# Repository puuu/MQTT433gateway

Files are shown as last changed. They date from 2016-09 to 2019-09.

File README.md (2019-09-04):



# MQTT433gateway

This Project implements a [MQTT](https://en.wikipedia.org/wiki/MQTT)
433.92MHz radio-frequency device gateway.  This is a IoT bridge to
couple popular RF devices like RC power-socket switches or weather
stations to internet capable devices like smartphone and tables.  In
this way they can be integrated into a home automation system.

The Software runs on a ESP8266 micro controller/WiFi chip and process
many 433.92MHz radio-protocols themselves.  The protocols are
processed utilizing the [ESPiLight](https://github.com/puuu/ESPiLight)
Arduino library which is a port of the [pilight](https://pilight.org/)
433.92MHz protocols to the Arduino platform.  The aim is to transmit,
receive and parse many 433.92MHz protocols directly on the device and
publish the results via MQTT.

A list of supported protocols can be found in the pilight manual:
https://manual.pilight.org/protocols/433.92/index.html

## Installation

Firmware binary are provided under
[releases](https://github.com/puuu/MQTT433gateway/releases). If you
want to build from source please have a look at
[Development](#development).  For the first flash you have multiple
possibilities, some of them are:

- Build and flash with PlatformIO (see [Development](#development))
- Flash with [esptool.py](https://github.com/espressif/esptool)
  ```console
  $ esptool.py --port <serialport> write_flash 0 mqtt433gateway_<env>-<version>.bin
  ```
- Flashing the `WebUpdater` example from
  [Arduino](https://github.com/esp8266/Arduino#installing-with-boards-manager)
  (File -> Examples -> ESP8266HTTPUpdateServer) and uploading the
  MQTT433gateway binary via browser.

At the moment two binaries are provided:
- `mqtt433gateway_esp12e-*.bin` generic ESP8266 module with cpu clock
  = 80 MHz (recommend)
- `mqtt433gateway_esp12e_160-*.bin` generic ESP8266 module with cpu
  clock = 160 MHz

The `platformio.ini` provides more environments, but the main
different between these are the way how they are flashed via serial
connector and how additional components (like LEDs) are
connected. Since MQTT433gateway can be fully configured by the web
frontend and provided [over-the-air programming](#ota-update), these
binaries should be sufficient.

## Hardware

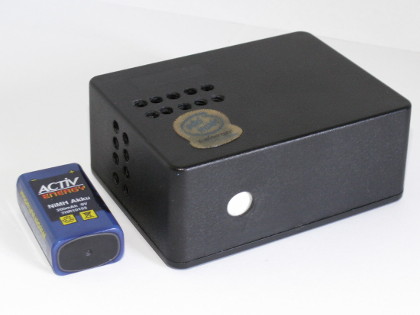
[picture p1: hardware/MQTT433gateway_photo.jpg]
MQTT433gateway box
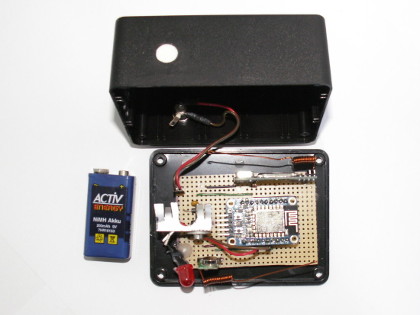
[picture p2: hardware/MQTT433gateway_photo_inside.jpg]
MQTT433gateway box open
 

The Software is primarily written for ESP8266 devices.  It is tested
with an
[Adafruit HUZZAH ESP8266](https://www.adafruit.com/product/2471), but
any other ESP8266 board should be fine too.  The circuitry can be
found in the [`hardware`](hardware/) folder.  The circuitry utilizes a separate 5V
voltage regulator.  This way it is possible to supply the
MQTT433gateway with up to 12V.  The 434MHz transmitter is directly
connected to the power-supply input, thus it can be driven with 12V
which enhances the transmitting range.  But powering with 12V also
means that the voltage regulator dissipates much power and a heat sink
is highly recommended.

For transmitting and receiving you need 434MHz-RF modules.  More
information can be found here:
- https://wiki.pilight.org/receivers
- https://wiki.pilight.org/senders
- https://github.com/sui77/rc-switch/wiki/List_TransmitterReceiverModules

If you are interested in a good receiving range, then I can not
recommend a WRL-10532 module.  I only achieved a range of about 5m
with it, after changing it against a RXB6 receiver, the range
increases to over 30m (including walls).

For the transmitter and receiver module you need separate antennas.
1/4 lambda (17cm) antennas are sufficient, but you may want to try
[coil loaded antennas](https://www.elektor.nl/Uploads/Forum/Posts/How-to-make-a-Air-Cooled-433MHz-antenna.pdf).

### LED status

The MQTT433gateway indicates its status by a LED:
- Connecting to WiFi/startup: Flashing at 1 Hz
- WiFiManager require WiFi configuration: Flashing at 5 Hz
- Device require configuration: Flashing at 0.5 Hz
- Normal operation: Heartbeat pulsing
- OTA Update: on during upload

## Configuration

The device is fully configurable through a web browser.  If you boot it for the
first time, it will create a WiFi access point (default ssid is `rf434`) where
you can connect to.  If you type in any url in your browser, you will get
directed to the WiFi configuration of the device.  You can select your network
here and fill in the credentials.

After that it will stop the access point and connect to your network.  There you
can either discover it via mDNS (default is `rf434.local`), ask your router for
the address of the device or check the serial console output.  If you type this
address in your browser, you'll see the main configuration frontend.  The
default username is `admin`, the default password is `MQTT433gateway`.

Please fill here your MQTT connection details. You can also change the topics
the device will subscribe and publish to.  In addition, all hardware related
settings, like connection pins of transmitter and receiver are configurable.

**Please note:** you have to change the configuration password! For security
reasons the device will not start working before this password is changed.

## MQTT/Automation

The MQTT433gateway communicates via MQTT, therefore a MQTT broker is needed,
e.g., [Mosquitto](https://mosquitto.org/). The topics for receiving and
transmitting can be configured with the `mqttReceiveTopic` and `mqttSendTopic`
settings. They default to `rf434/recv/` and `rf434/send/`, respectively.  It is
possible to use a common topic for multiple gateways in one network and thus to
expand the radio range.

After (re)connecting to the MQTT broker, the gateway sends the message
`{"version":"<git tag or hash>","chipId":"<chipId>"}` to the version
topic that is set in `mqttVersionTopic` as well as the message
`online` to the state topic that is set in `mqttStateTopic`.  In
addition, it registered with the last will set to the message
`offline` for the state topic. This allows to check the status of the
MQTT433gateway, e.g. as a availability topic in Home Assistant.

MQTT subscription is done to the topic `<mqttSendTopic><protocol>`.  The
messages to be transmitted must be a valid pilight JSON messages.  The setting
`mqttSendTopic` should end with a `/`.  `<protocol>` is the pilight protocol
name.  Additionally, `<protocol>` can be `RAW` to transmit a RAW signal similar
as used with the [pilight USB Nano](https://github.com/pilight/pilight-usb-nano/blob/master/pilight_usb_nano.c).

Received and decoded RF signals are published in the
`<mqttReceiveTopic><protocol>[/<id>]` topic as pilight JSON message.  To
avoid receiving errors, a message must be received at least twice
before it is published.  `<protocol>` is the pilight protocol name and
the optional `<id>` will be used if the pilight JSON message contains
an `id` attribute.

### Integration in Home Assistant

Here are some examples how to integrate the MQTT433gateway into
[Home Assistant](https://home-assistant.io).

Status of the MQTT433gateway:

```yaml
binary_sensor:
  - platform: mqtt
    state_topic: "rf434/state"
    name: "rf434"
    payload_on: "online"
    payload_off: "offline"
    device_class: connectivity
```

The message of a TCM 218943 weather station sensor looks like this:
`rf434/recv/tcm/108 {"id":108,"temperature":22.7,"humidity":50,"battery":1,"button":0}`.
A corresponding Home Assistant configuration is:

```yaml
sensor:
  - platform: mqtt
    state_topic: "rf434/recv/tcm/108"
    unit_of_measurement: "°C"
    name: "tcm_a_temp"
    value_template: '{{ value_json.temperature }}'
    device_class: temperature
    availability_topic: "rf434/state"
  - platform: mqtt
    state_topic: "rf434/recv/tcm/108"
    unit_of_measurement: "%"
    name: "tcm_a_humidity"
    value_template: '{{ value_json.humidity }}
    device_class: humidity
    availability_topic: "rf434/state"

binary_sensor:
  - platform: mqtt
    state_topic: "rf434/recv/tcm/108"
    name: "tcm_a_battery"
    sensor_class: power
    payload_on: 0
    payload_off: 1
    value_template: '{{ value_json.battery }}'
    device_class: battery
    availability_topic: "rf434/state"
```

Impulse RC socket switches, like many RC socket switches with DIP
switches:

```yaml
switch:
  - platform: mqtt
    name: "impuls_24_1"
    command_topic: "rf434/send/impuls"
    payload_on: '{"systemcode":24,"programcode":1,"on":1}'
    payload_off: '{"systemcode":24,"programcode":1,"off":1}'
    availability_topic: "rf434/state"
  - platform: mqtt
    name: "impuls_24_2"
    command_topic: "rf434/send/impuls"
    payload_on: '{"systemcode":24,"programcode":2,"on":1}'
    payload_off: '{"systemcode":24,"programcode":2,"off":1}'
    availability_topic: "rf434/state"
  - platform: mqtt
    name: "impuls_24_3"
    command_topic: "rf434/send/impuls"
    payload_on: '{"systemcode":24,"programcode":4,"on":1}'
    payload_off: '{"systemcode":24,"programcode":4,"off":1}'
    availability_topic: "rf434/state"
```

Elro 800 based RC socket switches:

```yaml
switch:
  - platform: mqtt
    name: "elro800_13_A"
    command_topic: "rf434/send/elro_800_switch"
    payload_on: '{"systemcode":13,"unitcode":1,"on":1}'
    payload_off: '{"systemcode":13,"unitcode":1,"off":1}'
    availability_topic: "rf434/state"
  - platform: mqtt
    name: "elro800_13_B"
    command_topic: "rf434/send/elro_800_switch"
    payload_on: '{"systemcode":13,"unitcode":2,"on":1}'
    payload_off: '{"systemcode":13,"unitcode":2,"off":1}'
    availability_topic: "rf434/state"
  - platform: mqtt
    name: "elro800_13_C"
    command_topic: "rf434/send/elro_800_switch"
    payload_on: '{"systemcode":13,"unitcode":4,"on":1}'
    payload_off: '{"systemcode":13,"unitcode":4,"off":1}'
    availability_topic: "rf434/state"
  - platform: mqtt
    name: "elro800_13_D"
    command_topic: "rf434/send/elro_800_switch"
    payload_on: '{"systemcode":13,"unitcode":8,"on":1}'
    payload_off: '{"systemcode":13,"unitcode":8,"off":1}'
    availability_topic: "rf434/state"
```

Quigg GT9000 based RC socket switches, e.g., Tevion GT-9000,
SilverCrest 91210 or Intertek Unitec 48110:

```yaml
switch:
  - platform: mqtt
    name: "gt9000_590715_0"
    command_topic: "rf434/send/quigg_gt9000"
    payload_on: '{"id":590715,"unit":0,"on":1}'
    payload_off: '{"id":590715,"unit":0,"off":1}'
    availability_topic: "rf434/state"
  - platform: mqtt
    name: "gt9000_590715_2"
    command_topic: "rf434/send/quigg_gt9000"
    payload_on: '{"id":590715,"unit":2,"on":1}'
    payload_off: '{"id":590715,"unit":2,"off":1}'
    availability_topic: "rf434/state"
  - platform: mqtt
    name: "gt9000_590715_3"
    command_topic: "rf434/send/quigg_gt9000"
    payload_on: '{"id":590715,"unit":3,"on":1}'
    payload_off: '{"id":590715,"unit":3,"off":1}'
    availability_topic: "rf434/state"
```

## OTA Update

Updates of the MQTT433gateway can be preformed by OTA (Over-the-air
programming) via the web frontend.  To do this, you need the binary
file that can be found under
[releases](https://github.com/puuu/MQTT433gateway/releases) or, if you
build with PlatformIO, at `<BUILD_DIR>/firmware.bin`,
e.g. `.pio/build/esp12e/firmware.bin`.

## Debugging/RF-protocol analyzing

The MQTT433gateway has a powerful logging system based on
[ArduinoSimpleLogging](https://github.com/janLo/ArduinoSimpleLogging).  Messages
for different log levels can be logged to serial interface, websocket (web
frontend) and syslog server.  The configuration can be done via web frontend.
The log messages could be very helpful for debugging.  In addition, RF-protocol
analyzing can be enabled with the `protocolRaw` debug flag.

## Protocol limitation

If you have the situation that there is a lot of noise in the air
and/or your device matches multiple protocols, you can limit the
available protocols.  This is easily possible with via the web frontend.

## Development

The software is using the [PlatformIO](http://platformio.org/) ecosystem. See their
[install instructions](http://docs.platformio.org/en/latest/installation.html) or get
their [IDE](http://docs.platformio.org/en/latest/ide/pioide.html) to get the
software. More information can be found in their [documentation](http://docs.platformio.org/en/latest/).

1. Open a terminal and go to the MQTT433Gateway project folder.

2. After that, decide for which board to create the firmware and give
   this as `--environment` to the platformio `run` command:
   ```console
   $ platformio run --environment <board>
   ```
   The available boards are defined in `platformio.ini`. Currently, this are
   + `esp12e` for ESP8266-12e/f models,
   + `esp12e_160` for ESP8266-12e/f models with cpu clock set to 160MHz,
   + `nodemcu` for NodeMCU 0.9 boards,
   + `nodemcuv2` for NodeMCU 1.0 boards,
   + `d1_mini`for D1 Mini boards,
   + `huzzah` for the Huzzah boards.

3. To flash the firmware to the board, connect the board to the PC via
   USB or a serial adapter. Make sure, it is the only device currently
   connected, as otherwise you might flash the wrong unit
   accidentally. Some boards need to be set manually into a programming
   mode, please check the manual of the board to get more details about
   how to do that.  The `platformio run` has the upload target to
   initialize flashing:
   ```console
   $ platformio run --environment <board> --target upload
   ```
   this will try to autodetect the serial port. If this is not
   successful, try
   ```console
   $ platformio run --environment <board> --target upload --upload-port <path-to-serial-port>
   ```

Older versions of MQTT433gateway were developed with the Arduino
IDE. You can find the old sources in the departed
[`arduino`](../../tree/arduino) branch.

## Contributions

If you find any bug, please feel free to fill an issue.  Also, pull request are
welcome.  More information can be found in the [contributing guide](CONTRIBUTING.md).

## Acknowledgement

Big thanks goes to the pilight community, which implemented all the
434MHz protocols.  If you want to integrate more protocols, please
contribute directly to [pilight](https://pilight.org/).

Many thanks goes to [@janLo](https://github.com/janLo), who developed the web
configuration interface.

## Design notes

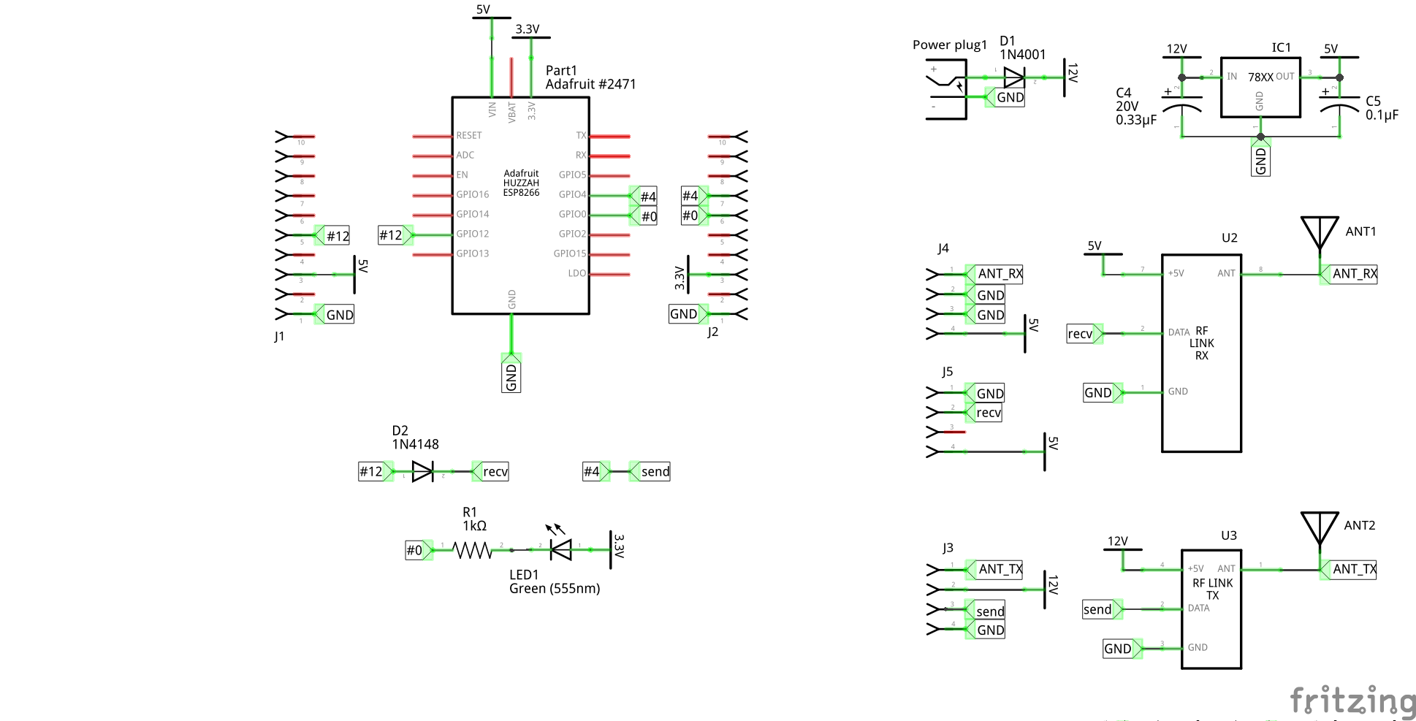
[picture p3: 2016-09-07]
hardware/MQTT433gateway_schem.png

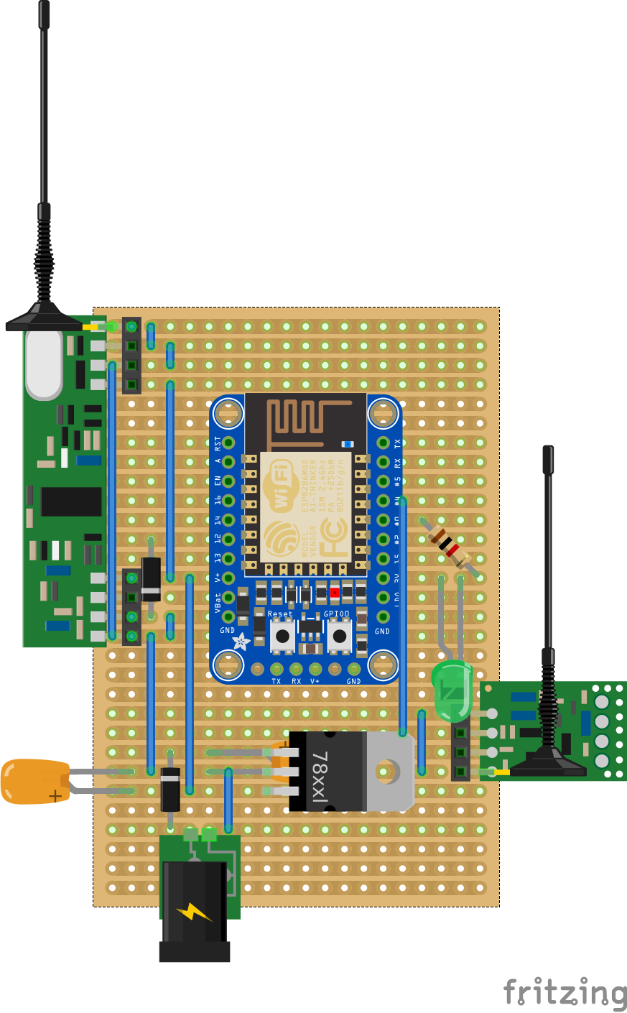
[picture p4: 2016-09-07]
hardware/MQTT433gateway_stripboard.png

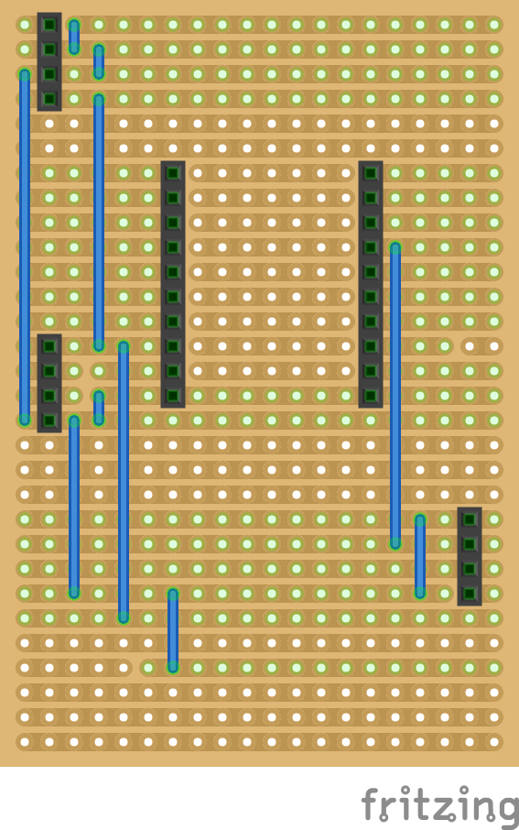
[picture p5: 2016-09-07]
hardware/MQTT433gateway_stripboard_only.png

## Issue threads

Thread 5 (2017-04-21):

ignored transmission

tvch, 2017-04-21:
hey there
after few hour of no transmission first transmission is ignored

I run it on a nodemcu with rxb6 receiver

any ideas
thanks

puuu, 2017-04-28:
Hi, thanks for using MQTT433gateway!

I could not observe such a behaviour.

What protocol you are using? Did you get any message on the serial interface?

You can try to increase the number of repeats that are sent out. Therefore, you have to change line [114](https://github.com/puuu/MQTT433gateway/blob/master/MQTT433gateway.ino#L114) in `MQTT433gateway.ino` to e.g.:
```c++
    rf.send(protocol, message, 20);
```
The default is 10 repeats.

tvch, 2017-04-28:
Thanks for your reply!

Now I realize that my problem probably wasnt good phrased: i've problems with receiving.

Any tips?

Tobi

puuu, 2017-04-28:
This behaviour I also can not observe. But it is difficult to test, because there is always a message arriving on 433 MHz, e.g., every 10 minutes from one of the weather stations in our house…

Please, can you tell, what protocol (including JSON message) you are using and if you get any message on the serial interface?

alexkirillov, 2018-03-23:
There is a problem with chineese "generic" receivers like these
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

in RfHandler::onRfCode status is never VALID.
So you can see the code in the (debug) log, but it never goes out to MQTT.
Commenting out this check makes it work fine, may be an option to disable this check should be added to the web settings page

puuu, 2018-03-24:
Most 433MHz protocols do not have any data integrity bits. They simply send the same message multiple time (e.g. more than 5 times).  To check the integrity of a message, [ESPiLight simply check if the same message arrived twice](https://github.com/puuu/ESPiLight/blob/master/src/ESPiLight.cpp#L364-L369) and mark it as `VALID`.

If your message only show up in the debug log, but is not marked as `VALID` it means that your receiver is not able to receive the messages correctly. In this case you are better to improve the signal-to-noise ratio, e.g. by optimizing the antenna and position of the gateway. Btw, as mentioned in the README, I can not recommend these receivers.

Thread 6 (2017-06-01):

Why avoid Gpio pins?

bphermansson, 2017-06-01:
The code says "const int RECEIVER_PIN = 12; //avoid 0, 2, 15, 16"

Why is this? I'm testing the code with a Esp-01 and want to use Gpio2.

torwag, 2017-06-01:
Simply because they are usually occupied by other functions:

For the Huzzah board, according to adafruits website:

GPIO #0, which does not have an internal pullup, and is also connected to both a mini tactile switch and red LED. This pin is used by the ESP8266 to determine when to boot into the bootloader. If the pin is held low during power-up it will start bootloading! That said, you can always use it as an output, and blink the red LED.

GPIO #2, is also used to detect boot-mode. It also is connected to the blue LED that is near the WiFi antenna. It has a pullup resistor connected to it, and you can use it as any output (like #0) and blink the blue LED.

GPIO #15, is also used to detect boot-mode. It has a pulldown resistor connected to it, make sure this pin isn't pulled high on startup. You can always just use it as an output

GPIO #16 can be used to wake up out of deep-sleep mode, you'll need to connect it to the RESET pin

If you use another board, you might or might not use those GPIOs, depending on the external circuitry (on board LEDs, switches, etc.)  and your needs (select boot-modes, wake-up, etc.). However, often those GPIOs might be the reason for trouble and head-scratching. Therefore, this little warning.

bphermansson, 2017-06-01:
Thanks for the answer! I discovered myself that using Gpio2 didn't work well on the Esp-01. So I made some modifications of the code to be able to use the 01, see my pull request.

puuu, 2017-06-02:
@torwag thank you for the detailed explanation, exactly this are the reasons for the comment.

Closed 2017-06-02.

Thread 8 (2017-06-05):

issues with RXB6 V2

tajsbjornsten, 2017-06-05:
Hi i have some strange issues with the MQTT433gateway.
When using an RXB6 with the NodeMCU 2 i don't receive anything if i switch to another cheap chinese rx module it works. but i really wanna use the RXB6 for better reception clear messages from my 433 devices. i have checked all the wiring and it is good.
If switch to raw mode i get something? See:

`rfESP_a39b1c/recvRaw c:00122314;p:1430,1034,757,1705,6029@
rfESP_a39b1c/recvRaw c:011234;p:5012,3736,3086,1389,10979@
rfESP_a39b1c/recvRaw c:012324506;p:283,4212,1014,3464,545,3921,8722@
rfESP_a39b1c/recvRaw c:01001010002;p:993,3550,15592@
rfESP_a39b1c/recvRaw c:012344;p:1130,3497,993,400,6926@
rfESP_a39b1c/recvRaw c:012234;p:1679,3477,1061,737,6642@
rfESP_a39b1c/recvRaw c:01234;p:1270,929,3543,671,8384@
rfESP_a39b1c/recvRaw c:011234115;p:3602,991,3487,699,3863,6021@
rfESP_a39b1c/recvRaw c:00102;p:950,3529,12936@
rfESP_a39b1c/recvRaw c:0123456;p:1959,868,3637,1007,1255,3994,6437@
rfESP_a39b1c/recvRaw c:012323224;p:386,3957,791,3580,13357@
rfESP_a39b1c/recvRaw c:01010102;p:817,3536,8474@
rfESP_a39b1c/recvRaw c:010101002;p:819,3542,13322@
rfESP_a39b1c/recvRaw c:01010102;p:896,3476,8392@
rfESP_a39b1c/recvRaw c:010101002;p:876,3487,13337@
rfESP_a39b1c/recvRaw c:01010102;p:870,3504,8437@
rfESP_a39b1c/recvRaw c:010101002;p:834,3514,13343@
rfESP_a39b1c/recvRaw c:01010102;p:847,3521,8427@
rfESP_a39b1c/recvRaw c:010101002;p:833,3523,13363@
rfESP_a39b1c/recvRaw c:01010102;p:842,3525,8441@
rfESP_a39b1c/recvRaw c:010101002;p:825,3507,13344@
rfESP_a39b1c/recvRaw c:01010102;p:849,3517,8451@
rfESP_a39b1c/recvRaw c:010101002;p:836,3517,13343@
rfESP_a39b1c/recvRaw c:01010102;p:844,3519,8449@
rfESP_a39b1c/recvRaw c:01010100101012;p:1010,3476,6032@
rfESP_a39b1c/recvRaw c:00102;p:1028,3504,6018@
rfESP_a39b1c/recvRaw c:010101001010123;p:1027,3464,1346,8213@
rfESP_a39b1c/recvRaw c:01010100101012;p:1016,3498,6020@
rfESP_a39b1c/recvRaw c:0100101012;p:994,3508,5984@
rfESP_a39b1c/recvRaw c:01010100101012;p:982,3517,6014@
rfESP_a39b1c/recvRaw c:01010100102;p:955,3520,8061@
rfESP_a39b1c/recvRaw c:010102010101345607;p:998,3518,4478,519,3036,2116,3885,6037@
rfESP_a39b1c/recvRaw c:01010100101012;p:989,3509,5979@
rfESP_a39b1c/recvRaw c:01234567;p:3095,1583,4480,265,882,679,1400,9353@
rfESP_a39b1c/recvRaw c:0101012;p:1068,3472,6024@
rfESP_a39b1c/recvRaw c:0101002;p:796,3563,13315@
rfESP_a39b1c/recvRaw c:01010102;p:861,3500,8440@
rfESP_a39b1c/recvRaw c:010101002;p:857,3515,13284@
rfESP_a39b1c/recvRaw c:01010102;p:917,3455,8368@
rfESP_a39b1c/recvRaw c:010101002;p:917,3448,13261@
rfESP_a39b1c/recvRaw c:01010102;p:906,3458,8371@
rfESP_a39b1c/recvRaw c:010101002;p:886,3479,13299@
rfESP_a39b1c/recvRaw c:01010102;p:900,3462,8387@
rfESP_a39b1c/recvRaw c:010101002;p:879,3493,13299@
rfESP_a39b1c/recvRaw c:01010102;p:895,3478,8404@
rfESP_a39b1c/recvRaw c:010101002;p:894,3459,13291@
rfESP_a39b1c/recvRaw c:01010102;p:885,3493,8399@
rfESP_a39b1c/recvRaw c:010101002;p:881,3484,13297@
rfESP_a39b1c/recvRaw c:01010102;p:885,3501,8399@
rfESP_a39b1c/recvRaw c:01234;p:1248,404,3582,2210,14301@
rfESP_a39b1c/recvRaw c:0101010010101234405;p:1045,3460,1798,3010,4639,5990@
rfESP_a39b1c/recvRaw c:010101001010123;p:1069,3413,3226,6365@
rfESP_a39b1c/recvRaw c:0101001010123;p:1053,3477,4786,11786@
rfESP_a39b1c/recvRaw c:0100101223134;p:1071,3460,3035,434,6588@
rfESP_a39b1c/recvRaw c:010100101234;p:1040,3435,680,3817,6076@
rfESP_a39b1c/recvRaw c:010101002;p:1084,3456,7996@
rfESP_a39b1c/recvRaw c:001010123;p:992,3462,4492,12012@
rfESP_a39b1c/recvRaw c:010101201010123245640278749:44;;p:1063,3458,3043,2473,787,1407,3282,379,914,183,500,8436@
rfESP_a39b1c/recvRaw c:01002;p:873,3497,13306@
rfESP_a39b1c/recvRaw c:01010102;p:910,3462,8377@
rfESP_a39b1c/recvRaw c:010101002;p:896,3427,13221@
rfESP_a39b1c/recvRaw c:01010102;p:980,3382,8307@
rfESP_a39b1c/recvRaw c:010101002;p:952,3409,13237@
rfESP_a39b1c/recvRaw c:01010102;p:942,3424,8368@
rfESP_a39b1c/recvRaw c:010101002;p:923,3374,13264@
rfESP_a39b1c/recvRaw c:01010102;p:931,3430,8350@
rfESP_a39b1c/recvRaw c:010101002;p:921,3430,13256@
rfESP_a39b1c/recvRaw c:01010102;p:922,3422,8358@
rfESP_a39b1c/recvRaw c:010101002;p:915,3436,13261@
rfESP_a39b1c/recvRaw c:01010102;p:925,3445,8360@
rfESP_a39b1c/recvRaw c:010101002;p:909,3435,13258@
rfESP_a39b1c/recvRaw c:01010102;p:938,3437,8369@
rfESP_a39b1c/recvRaw c:00120203456;p:2919,4193,1790,492,2792,3409,13156@
rfESP_a39b1c/recvRaw c:012123;p:808,3348,1162,7951@
rfESP_a39b1c/recvRaw c:0010101230405;p:1124,3425,653,3047,4796,5966@
rfESP_a39b1c/recvRaw c:012202302024567;p:1092,4419,3433,608,900,3628,1598,15036@
rfESP_a39b1c/recvRaw c:01210321442156;p:425,3422,1078,4028,4409,1817,14774@
rfESP_a39b1c/recvRaw c:0010123;p:1066,3418,1472,15127@
rfESP_a39b1c/recvRaw c:010123001014516;p:1088,3420,349,4242,685,3867,13136@
rfESP_a39b1c/recvRaw c:0010102;p:1073,3448,5963@
rfESP_a39b1c/recvRaw c:010100101012;p:1090,3406,5809@
rfESP_a39b1c/recvRaw c:0102010020201343456;p:1098,3564,3445,2548,337,553,7709@
rfESP_a39b1c/recvRaw c:01234256789;p:4320,358,3277,4615,3014,959,1101,3746,1511,5379@
rfESP_a39b1c/recvRaw c:01123;p:2171,171,1083,10522@
rfESP_a39b1c/recvRaw c:0101023045;p:1122,3395,728,3803,382,14153@
rfESP_a39b1c/recvRaw c:00123;p:3457,235,1120,7957@
rfESP_a39b1c/recvRaw c:01234;p:2275,3627,1413,1060,5958@
rfESP_a39b1c/recvRaw c:001023;p:1147,3412,851,12730@
rfESP_a39b1c/recvRaw c:01123;p:4739,4541,669,6418@
rfESP_a39b1c/recvRaw c:0100102;p:1087,3403,7986@
rfESP_a39b1c/recvRaw c:0101010010101223456;p:1102,3399,2875,207,3597,560,6451@
rfESP_a39b1c/recvRaw c:012303004;p:1097,4298,217,3411,12462@
rfESP_a39b1c/recvRaw c:012334;p:343,3670,2953,919,8412@
rfESP_a39b1c/recvRaw c:01002;p:863,3474,13275@
rfESP_a39b1c/recvRaw c:01010102;p:924,3423,8363@
rfESP_a39b1c/recvRaw c:010101002;p:939,3416,13221@
rfESP_a39b1c/recvRaw c:01010102;p:982,3373,8279@
rfESP_a39b1c/recvRaw c:010101002;p:962,3395,13209@
rfESP_a39b1c/recvRaw c:01010102;p:955,3410,8340@
rfESP_a39b1c/recvRaw c:010101002;p:942,3427,13235@
rfESP_a39b1c/recvRaw c:01010102;p:949,3425,8349@
rfESP_a39b1c/recvRaw c:010101002;p:910,3447,13231@
rfESP_a39b1c/recvRaw c:01010102;p:936,3431,8341@
rfESP_a39b1c/recvRaw c:010101002;p:933,3425,13250@
rfESP_a39b1c/recvRaw c:01010102;p:939,3429,8341@
rfESP_a39b1c/recvRaw c:010101002;p:931,3417,13234@
rfESP_a39b1c/recvRaw c:01010102;p:944,3419,8345@
rfESP_a39b1c/recvRaw c:01231405;p:2925,746,1062,1490,418,5238@
rfESP_a39b1c/recvRaw c:01234;p:3325,4215,546,3684,6617@
rfESP_a39b1c/recvRaw c:01234;p:522,2147,1775,1174,5850@
rfESP_a39b1c/recvRaw c:01010120101012;p:1108,3392,6170@
rfESP_a39b1c/recvRaw c:00102;p:1140,3383,7913@
rfESP_a39b1c/recvRaw c:010120101013;p:1093,3389,562,5518@
rfESP_a39b1c/recvRaw c:010101002;p:1115,3361,7912@
rfESP_a39b1c/recvRaw c:01213;p:4627,1267,3452,10369@
rfESP_a39b1c/recvRaw c:010101001010123;p:1115,3365,4038,12529@
rfESP_a39b1c/recvRaw c:00101010010102;p:1112,3355,5672@
rfESP_a39b1c/recvRaw c:010101001010123;p:1110,3385,2743,6819@
rfESP_a39b1c/recvRaw c:01010100101012344567108936:;;p:1116,3373,2520,2968,1966,556,442,2779,732,1349,1814,6906@
rfESP_a39b1c/recvRaw c:010101002;p:901,3460,13236@
rfESP_a39b1c/recvRaw c:01012;p:960,3388,5779@
rfESP_a39b1c/recvRaw c:010101002;p:957,3401,13179@
rfESP_a39b1c/recvRaw c:01012;p:1021,3334,5823@
rfESP_a39b1c/recvRaw c:010101002;p:1007,3368,13203@
rfESP_a39b1c/recvRaw c:01012;p:982,3376,5791@
rfESP_a39b1c/recvRaw c:010101002;p:977,3394,13231@
rfESP_a39b1c/recvRaw c:01012;p:971,3387,5807@
rfESP_a39b1c/recvRaw c:010101002;p:963,3401,13212@
rfESP_a39b1c/recvRaw c:01012;p:979,3382,5786@
rfESP_a39b1c/recvRaw c:010101002;p:977,3390,13215@
rfESP_a39b1c/recvRaw c:01012;p:976,3387,5791@
rfESP_a39b1c/recvRaw c:010101002;p:970,3385,13203@
rfESP_a39b1c/recvRaw c:012345;p:977,3379,3830,589,1157,15382@
rfESP_a39b1c/recvRaw c:0100101234;p:1148,3326,4540,2205,7388@
rfESP_a39b1c/recvRaw c:012322323456789;p:469,4062,1133,3391,841,3697,298,4713,978,10605@
rfESP_a39b1c/recvRaw c:0100101010010123;p:1137,3345,618,9255@
rfESP_a39b1c/recvRaw c:010101010101203;p:1143,3340,2427,5895@
rfESP_a39b1c/recvRaw c:010120103;p:1139,3354,493,7923@
rfESP_a39b1c/recvRaw c:01232323425;p:4532,983,1121,3405,631,5872@
rfESP_a39b1c/recvRaw c:01010100102;p:1140,3367,7896@
rfESP_a39b1c/recvRaw c:01234;p:4736,710,4031,1263,5801@
rfESP_a39b1c/recvRaw c:01221212134;p:277,3392,1126,3018,6445@`

I have tired the RXB6 with another sketch (OpenMQTTGateway) and i am receiving fine.

torwag, 2017-06-06:
Most of the messages look like noise to me. Thus, it seems there is something wrong. I am using an RXB6 myself without any problems. Antenna?

puuu, 2017-06-06:
Hi @tajsbjornsten,
thank you for the data of the RAW mode. I need some more information.

Is the hardware connection (RXB6 to ESP) of both sketch the same? Please write how they are connected.

From the RAW data, it looks like, the ESP get data from the RXB6. Unfortunately, the RAW mode is very noisy and most information are to short do be a real signal. Did you send signal (e.g. pressing a button of a rc-remote) during this recording? Please tell about the transmitter.

If possible please send the output with enabled raw mode by using the working rx module and utilising the same transmitter.

tajsbjornsten, 2017-06-07:
Hi @puuu

Here is the RAW data where i am pushing a buttom on an 434 rf remote
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
torwag, 2017-06-07:
The raw protocol still looks like random noise to me.
The receiver works in a way, that it increases it's gain close to the noise level. As soon as a real message comes in, gain is reduced.
Beside of a longer message you should be able to observe a short period of silence after receiving a real message, as the receiver waits a bit before it starts to increase the gain again.
A typical raw message should start with c: and then a long column of numberd usually all are 0 1 and maybe sometimes a 2 at the beginning or the end.  These number represent the time width of the puls train. The numbers after that are those different pulse length. Usually a protocol uses only a few different pulse widths. A pattern should be observable. Esp. if you press the transmitter button several times you should see the exact same message.
As your datagrams seems to be much to short, it seems you receive data from the unit but it is not valid.
However, i have no idea why it works with another sketch on the exact same setup. Is it exactly the same?

puuu, 2017-06-08:
Hi @tajsbjornsten,
unfortunately, with this information I only can guess. The data seems to be only noise, but without any connection, there is no noise…

> the wiring is going from D1 on the NodeMCU to the RXB6's Data pin ( i have changed it in the sketch )

So you directly connected D1 with the data pin? And supply the RXB6 with 5V?

Be warned, the GPIOs of the ESP8266 are not 5V save. It may work, but there is no warranty. That is why I suggest in the [schematic](https://github.com/puuu/MQTT433gateway/blob/master/hardware/MQTT433gateway_schem.png) a protection with a diode. Therefore, the [input pin is set to pullup](https://github.com/puuu/MQTT433gateway/blob/master/MQTT433gateway.ino#L73). Since the other sketch did not set the pin to pullup, this could be your problem.

So please try either to disable the pullup (be warned) or try the protection circuitry.

tajsbjornsten, 2017-06-10:
Hi @puuu

i have change til #73 i the code til "INPUT" and now it works. The 5v to the GPIO doesn't seem to do any harm.

Closed 2017-06-10.

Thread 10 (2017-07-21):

Problem getting the code to work with arctech_switch

Trisk3lion, 2017-07-21:
I'm trying to get you code to work with a 3-pack of Telldus Slim RF outlets.
I begun with trying to sniff the codes, and this is what I get:

```
pulses: 132 possible protocol: arctech_switch
RF signal arrived [arctech_switch][52381518] (3) {"id":52381518,"unit":15,"state":"off"}
pulses: 132 possible protocol: arctech_screen
RF signal arrived [arctech_screen][52381518] (3) {"id":52381518,"unit":15,"state":"down"}
pulses: 132 possible protocol: arctech_contact
RF signal arrived [arctech_contact][52381518] (3) {"id":52381518,"unit":15,"state":"closed"}

pulses: 132 possible protocol: arctech_switch
RF signal arrived [arctech_switch][52381518] (0) {"id":52381518,"unit":15,"state":"on"}
pulses: 132 possible protocol: arctech_screen
RF signal arrived [arctech_screen][52381518] (0) {"id":52381518,"unit":15,"state":"up"}
pulses: 132 possible protocol: arctech_contact
RF signal arrived [arctech_contact][52381518] (0) {"id":52381518,"unit":15,"state":"opened"}
```

for off and on respectively. So i tried to set it up in my config file like this:

```
switch:
  - platform: mqtt
    name: "arctech_switch"
    command_topic: "rf434/send/arctech_switch"
    payload_on: '{"id":52381518,"unit":15,"on":1}'
    payload_off: '{"id":52381518,"unit":15,"off":1}'
```

But it is not really working as it should, the outlets isn't turning either on or off. This is what I get when I subscribe to the topic:

```
Client mosqsub|2882-hassbian received PUBLISH (d0, q0, r0, m0, 'rf434/send/arctech_switch', ... (32 bytes))
{"id":52381518,"unit":15,"on":1}
Client mosqsub|2882-hassbian received PUBLISH (d0, q0, r0, m0, 'rf434/recv/arctech_switch/52381518', ... (38 bytes))
{"id":52381518,"unit":15,"state":"on"}
Client mosqsub|2882-hassbian received PUBLISH (d0, q0, r0, m0, 'rf434/recv/arctech_screen/52381518', ... (38 bytes))
{"id":52381518,"unit":15,"state":"up"}
Client mosqsub|2882-hassbian received PUBLISH (d0, q0, r0, m0, 'rf434/recv/arctech_contact/0', ... (34 bytes))
{"id":0,"unit":0,"state":"closed"}
```
It looks like the last line with arctech_contact is not getting the correct id and unit. Do you have any idea of what could be wrong or could be done?
Or maybe it is more of question to the PiLight guys/guy?

puuu, 2017-07-26:
This looks like, your RF outlets are not supported by pilight. The `arctech_switch` may be very similar to the protocol of your outlet.

The MQTT433gateway uses ESPilight which use the RF protocols as they are in the development branch of pilight. Any protocol development should be done by pilight. Usually, this requires discussion on the [piligh forum](https://forum.pilight.org/).

You can enable the RAW mode of MQTT433gateway to get raw signal and observe the differences. In your case it could be a simple timing problem and you can try to tweak `AVG_PULSE_LENGTH` in `libs/pilight/protocols/433.92/arctech_switch.c`.

orrpan, 2017-10-02:
had exactly same problem with nexa pe-3, installed pilight from development branch on my RPi2 worked without without.

puuu, 2017-10-02:
Please can you give us more details.

What protocol you are using for the nexa pe-3? Also `arctech_switch`?

It could be timing problems. Can you play with the `AVG_PULSE_LENGTH` in the  `src/pilight/libs/pilight/protocols/433.92/arctech_switch.c` file of the ESPiLight library? For example set it to 300 and then, recompile and flash MQTT433gateway again.

orrpan, 2017-10-02:
ESP:
No, I tried it but nothing happen. I tried with these arctech_switch, arctech_screen, arctech_contact or nexa_switch, have some other elro_800_switch that worked.

PI:
I use nexa_switch (ish se below) on the raspberry pi.

I can try it later today.

My config for home assistant that is connected to pilight. Two examples, one for all units (actually works for on and off, even tho remote only has an "all off"-button) and one for one unit.
 ```
- platform: pilight
   switches:
    all_nexa:
      on_code:
        protocol: nexa_switch
        all: 1
        id: 25602690
        'on': 1
      off_code:
        protocol: nexa_switch
        all: 1
        id: 25602690
        'off': 1
      on_code_receive:
        protocol: arctech_switch
        all: 1
        id: 25602690
        state: 'on'
      off_code_receive:
        protocol: arctech_switch
        all: 1
        id: 25602690
        state: 'off'
    nexa0:
      on_code:
        protocol: nexa_switch
        unit: 0
        id: 25602690
        'on': 1
      off_code:
        protocol: nexa_switch
        unit: 0
        id: 25602690
        'off': 1
      on_code_receive:
        protocol: arctech_switch
        unit: 0
        id: 25602690
        state: 'on'
      off_code_receive:
        protocol: arctech_switch
        unit: 0
        id: 25602690
        state: 'off'
```

orrpan, 2017-10-02:
okey must have done wrong yesterday, this worked

```
- platform: mqtt
  name: arctech_switch_test
  command_topic: "rf434/send/arctech_switch"
  payload_on: '{"id": 25602690,"unit":2,"on":1}'
  payload_off: '{"id": 25602690,"unit":2,"off":1}'
```

puuu, 2017-10-03:
Thank you for giving feedback of succeed.
So, the `arctech_switch` protocol works for you without changing a file in the ESPiLight library?

Btw, were both tests done with the same version of ESPiLight?

orrpan, 2017-10-03:
Yes, no changes. Didn't even re-flash it

Closed 2017-12-12.

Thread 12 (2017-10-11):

Problem to work with arctech_switch_old

ratawit, 2017-10-11:
I have a problem to get code from rf remote. I got code when pressing button:
`pulses: 50 possible protocol: arctech_switch_old
pulses: 50 possible protocol: arctech_switch_old
pulses: 50 possible protocol: arctech_switch_old
pulses: 50 possible protocol: arctech_switch_old`

I tried to get code from another rf remote. These what I got:
`pulses: 50 possible protocol: rev3_switch
RF signal arrived [rev3_switch]/[33] (0) {"id":33,"unit":13,"state":"on"} (1)
pulses: 50 possible protocol: ev1527
RF signal arrived [ev1527]/[] (0) {"unitcode":1031337,"state":"opened"} (1)
pulses: 50 possible protocol: rev3_switch
RF signal arrived [rev3_switch]/[33] (2) {"id":33,"unit":13,"state":"on"} (102)
pulses: 50 possible protocol: ev1527
RF signal arrived [ev1527]/[] (2) {"unitcode":1031337,"state":"opened"} (102)`

And I got code from 433Mhz door sensor as these:
`pulses: 50 possible protocol: rsl366
pulses: 50 possible protocol: arctech_switch_old
pulses: 50 possible protocol: rsl366
pulses: 50 possible protocol: arctech_switch_old`

What should I do to get them work?

Thanks.

puuu, 2017-12-20:
@ratawit sorry for the late reply, I totally missed this issue.
Are you sure that this is a `arctech_switch_old` remote?
The output only indicates the pulse behaviour is similar, but the missing `RF signal arrived` shows that it could not be encoded by this protocol module. The same is for your door sensor.

Probably, the protocols are not yet supported by pilight. Please have a look [here](https://github.com/puuu/ESPiLight#new-protocols), how to report new protocols.

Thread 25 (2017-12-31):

Error: Detected unknown package

LightIsLife, 2017-12-31:
I have just tried to install platfromIO on Atom and on VSCode, as well as just the core (all on a MAC) without success. Not sure whether this is the right forum, but just the core installation following the manual results in permission errors (despite using sudo and having verified that I indeed have python 2.7) and VScode and Atom both report back the error: Error: Detected unknown package ..... with any of the packages (nodemcu, nodemcu2, huzzaah, etc) [I actually tried them all]; searching the wisdom of the internet revealed that this is an error for which there is a bounty; I have also checked that no updates are available; "pio platform lists" does not reveal any info, here the complete output:
`
espressif8266 ~ Espressif 8266
==============================
Espressif Systems is a privately held fabless semiconductor company. They provide wireless communications a
nd Wi-Fi chips which are widely used in mobile devices and the Internet of Things applications.

Home: http://platformio.org/platforms/espressif8266
Frameworks: arduino, esp8266-nonos-sdk, esp8266-rtos-sdk, simba
Packages: framework-esp8266-rtos-sdk, toolchain-xtensa, framework-simba, tool-esptool, tool-mkspiffs, tool-
espotapy, framework-arduinoespressif8266, sdk-esp8266, framework-esp8266-nonos-sdk
Version: 1.5.0
`
(just as some posts where recommending to find a number that would allow to specify the package in terms of nodemcuv2@XXXXX)
what am I missing? Any and all help will be appreciated

puuu, 2018-02-23:
I did not saw any error like this, but I have no possibility to test it with a Mac. I tested with Linux and Atom (you can also check the [travis-ci logs](https://travis-ci.org/puuu/MQTT433gateway/jobs/345158117)). Please try again with the current master branch (with web frontend support) and the latest version of platformio.

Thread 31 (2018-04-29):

Compiling from source does not deliver working firmware

renearts, 2018-04-29:
First; thanks for this awesome piece of software. It was exactly what I have been looking for / wanting to put together myself for a few months. But I would never have been able to get even close to this project :)

That being said, today I downloaded the source in an attempt to debug a bit of MQTT / ESPilight as I was experiencing some trouble in trying to turn an arctech dimmer completely off (which is a different issue, I might try to debug it myself and send a pull request or file another issue).
After installing the Platformio IDE and the necessary libraries I was able to compile the project. Though when uploading it (succesfully) to my NodeMCUv2 board the following error appeared:
```
ets Jan  8 2013,rst cause:2, boot mode:(3,6)

load 0x4010f000, len 1384, room 16
tail 8
chksum 0x2d
csum 0x2d
v614f7c32
~ld
```

I tried uploading the binary file via the WebUploader sketch, as well as directly form the commandline with PlatformIO. Also did a clean install of PlatformIO on my other laptop and tried with a D1 mini R2 board as well. All yield the same boot loop as result.

While trying to figure this out by myself, I tried the following code which did work and after uncommenting the settings line started boot looping again.

```
#include <ESP8266httpUpdate.h>
#include <ESP8266mDNS.h>
#include <FS.h>

#include <ArduinoSimpleLogging.h>
#include <WiFiManager.h>

#include <ConfigWebServer.h>
#include <MqttClient.h>
#include <RfHandler.h>
#include <Settings.h>
#include <StatusLED.h>
#include <SyslogLogTarget.h>
#include <SystemHeap.h>
#include <SystemLoad.h>

WiFiClient wifi;

// Settings settings;
ConfigWebServer *webServer = nullptr;
MqttClient *mqttClient = nullptr;
RfHandler *rf = nullptr;
SyslogLogTarget *syslogLog = nullptr;
StatusLED *statusLED = nullptr;
SystemLoad *systemLoad = nullptr;
SystemHeap *systemHeap = nullptr;

void setup() {
    Serial.begin(115200);
    Serial.println("Hello world!");
    // Logger.addHandler(Logger.DEBUG, Serial);
}

void loop() {
    Serial.println("Hello world!");
    delay(1000);
}
```

Both laptops run Ubuntu 17.10, PlatformIO: Home 0.9.5·Core 3.5.3b1
Source from master branch on git; commit 5418b4ec6ceaf0ecb0e110ff2df3a86cab444429 (HEAD -> master, tag: v0.1.0, origin/next, origin/master, origin/HEAD)

puuu, 2018-05-22:
Thank your for trying MQTT433gateway!

Please try the binary from [releases](/puuu/MQTT433gateway/releases)?

I can not reproduce this issue. Your output looks like a crash at boot time. May be your power supply is not sufficient.

renearts, 2018-05-23:
The binary works fine generally, though as I experienced some problems with sending dimmer commands via MQTT I was trying to debug I ran into this problem.

onkelbeh, 2018-09-02:
Same here with PlatformIO 3.6.1a1 running in Atom.io 1.3, OS X High Sierra 10.13.6. Got a bunch of older Intertechno plugs, and imho the Intertechno definition is missing in ESPiLight 0.14.2, tried to compile the original version first. Hardware is a ESP8266 ESP-12E CP2102, tried it with nodemcuv2.bin and esp12e.bin, either flashed with Aton and pyFlasher 3.0 in DOUT mode. The binary release (esp12e-v0.1.0.bin) worked out of the box with the same settings, but is unfortunately without the driver for the Intertechnos. Perhaps someone could merge the actual pilight libs in ESPiLight and make a fresh binary?

janLo, 2018-09-05:
Try to erase the chip first. I cannot reproduce the problem but if its "fixed" by commenting the settings loading it seems that it loads some old config that isn't really a config. This can happen when the layout in the flash-chip changes maybe because of an incompatible version of the esp toolchain to the one the original FW was build with.

You can erase the flash using the `esptool` that should be somewhere in your `.platformio` dir (e.g. `~/.platformio/packages/tool-esptool/esptool`. I think the option to erase the chip was `-ce` but I havn't done it for a while - try `-h` to get the help. There is also a python-wrapper out there, that is a bit more user-friendly (search for `esptool.py`). And don't worry, you cannot "break" the chip with erasing the flash. The boot-from-uart works independent from it by pulling on some GPIOs (see https://github.com/espressif/esptool/wiki/ESP8266-Boot-Mode-Selection for details).

puuu, 2018-11-02:
I believe, this bug is now fixed. See edbb64a76601032941498039b6e8b5990e9391a0 .

renearts, 2018-11-05:
Indeed; this seems fixed. Awesome work and thanks again for this amazing project!

Closed 2018-11-02.

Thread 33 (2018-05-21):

Correct way of sending raw signals

subzero79, 2018-05-21:
I am trying to improve my current setup for fan speed control by using this gateway. ATM I use pilight USB nano which works.

I have 4 ceiling fans, each of them has 6 speeds, plus stop  and a light buttons. I have recorded all the raw codes of each button for each fan, so i have a json file that maps the devices, their speeds and their respective raw code.

In pilight the raw command can be send ```pilight-send -p raw -c "RAWCODECOMMAND"```, in my case they look like this

```pilight-send -p raw -c "370 370 370 370 370 370 370 370 370 370 370 670 370 730 370 670 370 670 370 670 370 670 370 370 370 11590"```

That toggles the fan light for example.

So for sending a raw command using the gateway i am using this mqtt publish command:

```mosquitto_pub -V mqttv311 -u homeassistant -P password -h localhost -t "rf434/send/RAW/" -m "370 370 370 370 370 370 370 370 370 370 370 670 370 730 370 670 370 670 370 670 370 670 370 370 370 11590"```

But seems like is not interpreted correctly by the gateway. When I move the transmitter to the current pilight nano setup and fire the raw code mentioned above, the gateway listening on raw codes reads this:

```
Set debug flag protocolRaw: 1
RAW RF signal (34): c:0122324563636363636222222222222327;p:1469,1105,430,176,754,4772,585,11409@
RAW RF signal (28): c:0101010110100012111000003104;p:552,210,807,380,11407@
RAW RF signal (32): c:01221202222002110130300001230204;p:454,304,157,790,11380@
RAW RF signal (30): c:012013311110011011100000000104;p:574,168,765,441,11408@
RAW RF signal (25): c:0101012202023000000000104;p:559,183,441,816,11414@
RAW RF signal (28): c:0111210113210014230000000105;p:544,194,312,673,899,11427@
RAW RF signal (26): c:01010222022013000320000104;p:548,189,329,747,11424@
RAW RF signal (28): c:0101020021000023200000111104;p:548,192,332,939,11429@
RAW RF signal (26): c:01201300311000000000000104;p:545,198,704,339,11446@
Webserver: debug PUT
Set debug flag protocolRaw: 0
```
What is the correct way of sending raw codes via mqtt?

I am using a nodemcu board. Firmware was compiled with visual studio (platformio).
The transmitter is XKFST module powered by the nodemcu 3.3V pin.

puuu, 2018-05-22:
Thank your for using MQTT433gateway!

To use RAW mode, your message must look like the Log messages you receive:
In your case  (`"370 370 370 370 370 370 370 370 370 370 370 670 370 370 370 670 370 670 370 670 370 670 370 370 370 11590"`) it must be:
```
c:00000000000100010101010002;p:370,670,11590@
```

The list of available pulse length is at `p:` and `c:` index to them (starting from 0).

subzero79, 2018-05-22:
Thanks for the time and the explanation.

That looks complex to translate I have 28 codes to deal with. Do you know of any script or library available to translate those codes into that format?

Atm I will try to send this single code but I am under serious doubt that my transmitter is working in nodemcu because the receiver doesn’t get anything when sending signals. It works in Pilight nano, not in the nodemcu. I’ve already ordered another transmitter to keep testing.

puuu, 2018-05-22:
> Do you know of any script or library available to translate those codes into that format?

Not a script, but [`ESPiLight::pulseTrainToString()`](https://github.com/puuu/ESPiLight/blob/master/src/ESPiLight.cpp#L385) implement it.

subzero79, 2018-05-23:
Thanks, i've looked at the coded (i am not a programmer, but i can read it) so i opted for php, here is a small script if someone needs this in the future.

```
#!/usr/bin/php
<?php

array_splice($argv, 0, 1);
$pulse_train = $argv;
$argv = array_unique($argv);
$uniqueElements = array_splice($argv,0,count(array_unique($argv)));

$pulse_lengths = "";
foreach ($pulse_train as $v) {
	$pulse_lengths .= array_search($v, $uniqueElements);
}

$pulse_index = implode(",", $uniqueElements);
$pulseString = sprintf("c:%s;p:%s@",$pulse_lengths,$pulse_index);
print($pulseString);
```
./pulseTraintoString.php 370 370 370 370 370 370 370 370 370 370 370 670 370 370 370 670 370 670 370 670 370 670 370 370 370 11590

The arguments do not need to be quoted as php will parse the whole as an array an each one will be an element of the array.

lokomotionn, 2018-05-26:
How to receive a RAW signal. the topic does not work  "rf434/recv/RAW/"

subzero79, 2018-06-12:
Do you have any recommendations on a transmitter module? I now have a got a STX888/SRX882, and again just the receiver works. BTW i am powering the module via 3.3V pin in the nodemcu.

Closed 2018-06-26.

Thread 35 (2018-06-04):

Join forces with OpenMQTTGateway

torwag, 2018-06-04:
There is another MQTT-Gateway project under active development.

https://github.com/1technophile/OpenMQTTGateway

I believe that both projects address the same idea.
They both developed in different directions

Differences to the MQTT433Gateway
1. Supports officially ESP32 and ESP8266
2. Supports other hardware, BLE, IR, direct Sensors, RFM69, GSM, etc.
3. Programming structure keeps it open for other Protocols as well (Zigbee, Zwave, Enocean)

Differences of this project to the OpenMQTTGateway
1. User interface for configuration (now very newbie friendly)
2. Uses the an own version of the pilight lib and hence supports many 433 MHz devices

I think both projects would benefit from each other and we might have at the end an ultimate Foo2MQTT-Gateway system, which ideally is even newbie friendly enough for non-programmers.

renearts, 2018-06-04:
As far as I know the RC-switch library used in that project is not as good as ESPilight, it also does not support the newer KoKo protocols.

torwag, 2018-06-05:
Therefore, I would propose to join forces here... why not using the epsilight lib of this project but using the BLE, RFM69 and other modules of the OpenMQTT project. That would bring us the best of both projects

puuu, 2018-11-02:
All the magic towards parsing the rf signals will be performed with [ESPiLight](https://github.com/puuu/ESPiLight) which based on the protocol implementations of pilight.

[ESPiLight](https://github.com/puuu/ESPiLight) is intentionally a library by it's own. Every project is free to use this library and I will happily support this.

But keep in mind that pilight was not developed with micrcocontoller in mind and thus is relativly bulky and memory hungry.

Btw.  I would like to see ESPiLight support in [esphomelib](https://esphomelib.com/esphomeyaml/).

1technophile, 2018-11-02:
Hello,

Thanks for your library @puu, for your information we [integrated it into OMG a few weeks ag](https://github.com/1technophile/OpenMQTTGateway/pull/242)o:

Of course it will not work on an uno but we can use it with ESP.

torwag, 2018-11-02:
@1technophile you beat me, as I was just going to post this.
Now, in my opinion we have a project with a nice fancy GUI for config (even after flashing) and platformio support (which I find much better rather then the arduino gui, if only for the dependency checks).
And we have a project which goes much more further and above 433 MHz devices most important being BLE.
Maybe there are even more ways to join both projects?

puuu, 2018-11-06:
@1technophile cool, ESPiLight is already integrated into OpenMQTTGateway, this is amazing!

I had a short look into the integration. As I understood, you need to select between rcswitch and ESPiLight but can not run both with the same receiver/transmitter? I think, it would be interesting to receive/transmit with one implementation and parse with both. Unfortunately (as far as I understand), the raw data formats are different and rcswitch does not support impulse trains as implemented in ESPiLight. The [pulse trains (array of pulses in µs)](https://github.com/puuu/ESPiLight/blob/master/src/ESPiLight.h#L36) are at a lower abstraction level, then the rcswitch data formats. Thus, to provide interoperability between ESPiLight and rcswitch, pulse train support must be implemented into rcswitch.

If you interested in a web frontend, please have a look to this project or [blinkenhat](https://github.com/Retardigrades/blinkenhat). @janLo did a great job by implementing a lightweight rest api in combination with a feature full javascript web frontend.

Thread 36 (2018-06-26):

nodemcu v2 doesn't not receive any publish msg in recv topic

subzero79, 2018-06-26:
Being working on this now two months, i still cannot get the software to send a single rf signal via mqtt. I suspected the rf transmitter, but going now through the third different one i have doubts now on the fw.

I have tried the default release, as well as my own build binary. I have a couple of issues using the settings as changing the mqtt password, resulted in admin password defaulted so no RF. So i put all my passwords, topic, etc in settings.h

So far from reading the log i can see MQTT433gateway connects to the MQTT broker successfully, i can confirm this on the mosquitto server debug log seeing several messages from the device:

```
1530014897: Sending PINGRESP to rf434
1530014900: Received PINGREQ from DVES_375428
1530014900: Sending PINGRESP to DVES_375428
1530014900: Received PINGREQ from DVES_14C4FE
1530014900: Sending PINGRESP to DVES_14C4FE
1530014906: Received PUBLISH from DVES_375428 (d0, q0, r0, m0, 'sonoff/switch/lounge/tele/STATE', ... (156 bytes))
1530014906: Received PUBLISH from DVES_375428 (d0, q0, r0, m0, 'sonoff/switch/lounge/tele/SENSOR', ... (160 bytes))
1530014906: Sending PUBLISH to e9f3c689-6ac0-45de-aed5-cf41262004e8 (d0, q0, r0, m0, 'sonoff/switch/lounge/tele/SENSOR', ... (160 bytes))
1530014912: Received PINGREQ from milight-hub-1493872
1530014912: Sending PINGRESP to milight-hub-1493872
1530014912: Received PINGREQ from rf434
1530014912: Sending PINGRESP to rf434
1530014915: Received PINGREQ from DVES_375428
1530014915: Sending PINGRESP to DVES_375428
1530014915: Received PINGREQ from DVES_14C4FE
1530014915: Sending PINGRESP to DVES_14C4FE
1530014924: Received PINGREQ from mqtt_3672cb7d.1352a4
1530014924: Sending PINGRESP to mqtt_3672cb7d.1352a4
```

Now when i send any message  via mqtt, the gateway doesn't log anything. Looking at others peoples issues here the received message should be something like:

Message arrived bla bla
rf send bla bla

This is a simple command made from the payloads from the wiki to test i use:

```
mosquitto_pub  -h ha.lan -u homeassistant -P password -t "rf/send/impuls/" -m '{"systemcode":24,"programcode":2,"on":1}'
```
or
```
mosquitto_pub  -h ha.lan -u homeassistant -P password -t "rf/send/impuls" -m '{"systemcode":24,"programcode":2,"on":1}'
```

Message is published as i can see it my subscribe terminal. But yet the serial terminal or web console don't log anything at all. The second command topic without slash crashes the nodemcu as you can see in the serial log

```
Loading config file.
Applying config settings.
Change status LED config: pin=16 activeHigh=0
configPassword: password
*WM:
*WM: AutoConnect
*WM: Connecting as wifi client...
*WM: Using last saved values, should be faster
*WM: Connection result:
*WM: 3
*WM: IP Address:
*WM: 10.10.0.30
Configure logging.
RfHandler Instance created.
Configure WebServer.
Starting webserver and websocket server.
WebServer instance created.
Configure rfProtocols.
Configure rfEchoMessages.
Try to (re)connect to MQTT broker
MQTT connected.
MQTT subscribe to topic: rf/send/+
MQTT subscribed.
MQTT instance created.
MDNS service registered.
Change status LED config: pin=16 activeHigh=0
Current configuration:
{
  "deviceName": "rf434",
  "mqttBroker": "10.10.0.152",
  "mqttBrokerPort": 1883,
  "mqttUser": "homeassistant",
  "mqttRetain": false,
  "mqttReceiveTopic": "rf/recv/",
  "mqttSendTopic": "rf/send/",
  "rfEchoMessages": false,
  "rfReceiverPin": 12,
  "rfTransmitterPin": 4,
  "rfReceiverPinPullUp": true,
  "rfProtocols": [],
  "serialLogLevel": "debug",
  "webLogLevel": "debug",
  "syslogLevel": "",
  "syslogHost": "",
  "syslogPort": 514,
  "ledPin": 16,
  "ledActiveHigh": false
}
Listen on IP: 10.10.0.30
Websocket client 0 connected

Exception (9):
epc1=0x40229f03 epc2=0x00000000 epc3=0x00000000 excvaddr=0x566e6b32 depc=0x00000000

ctx: cont
sp: 3fff1e10 end: 3fff2050 offset: 01a0

>>>stack>>>
3fff1fb0:  3fff1fe0 00000001 0000000e 402188a2
3fff1fc0:  3fff6e9c 3fff6ae0 00000000 40219032
3fff1fd0:  732f6672 2f646e65 75706d69 4000736c
3fff1fe0:  00000001 3fff0dc4 3fff69b0 4020a20d
3fff1ff0:  401065e0 00000000 00001388 3fff1020
3fff2000:  00000000 00000000 3fff6ae0 3fff1020
3fff2010:  3fff0dc0 3fff0dc4 3fff7e24 4020f1a9
3fff2020:  00000000 00000000 3fff0db8 4022b59d
3fff2030:  3fffdad0 00000000 3fff1019 40211100
3fff2040:  feefeffe feefeffe 3fff1030 402134b0
<<<stack<<<

 ets Jan  8 2013,rst cause:2, boot mode:(3,7)

load 0x4010f000, len 1384, room 16
tail 8
chksum 0x2d
csum 0x2d
v00000000
~ld
Load Settings...
Loading config file.
Applying config settings.
Change status LED config: pin=16 activeHigh=0
configPassword: password
*WM:
*WM: AutoConnect
*WM: Connecting as wifi client...
*WM: Using last saved values, should be faster
*WM: Connection result:
*WM: 3
*WM: IP Address:
*WM: 10.10.0.30
Configure logging.
RfHandler Instance created.
Configure WebServer.
Starting webserver and websocket server.
WebServer instance created.
Configure rfProtocols.
Configure rfEchoMessages.
Try to (re)connect to MQTT broker
MQTT connected.
MQTT subscribe to topic: rf/send/+
MQTT subscribed.
MQTT instance created.
MDNS service registered.
Change status LED config: pin=16 activeHigh=0
Current configuration:
{
  "deviceName": "rf434",
  "mqttBroker": "10.10.0.152",
  "mqttBrokerPort": 1883,
  "mqttUser": "homeassistant",
  "mqttRetain": false,
  "mqttReceiveTopic": "rf/recv/",
  "mqttSendTopic": "rf/send/",
  "rfEchoMessages": false,
  "rfReceiverPin": 12,
  "rfTransmitterPin": 4,
  "rfReceiverPinPullUp": true,
  "rfProtocols": [],
  "serialLogLevel": "debug",
  "webLogLevel": "debug",
  "syslogLevel": "",
  "syslogHost": "",
  "syslogPort": 514,
  "ledPin": 16,
  "ledActiveHigh": false
}
Listen on IP: 10.10.0.30
Websocket client 0 connected

```

So clearly the second command should be the correct one as the gw seems to receive it, but something is not working.

Can you clarify if not even having the transmitter connected  to the gw should still try send the code right and of course log it right?

puuu, 2018-11-06:
The trailing `/` is too much. Also, for debugging it is not required to connect any transmitter/receiver on the esp. You should still see the debug messages.

Here is an example (`"mqttReceiveTopic": "rf/recv/", "mqttSendTopic": "rf/send/", "serialLogLevel": "debug"`):

```cmd
$ mosquitto_pub -t "rf/send/impuls" -m '{"systemcode":24,"programcode":2,"on":1}'
```

Serial console:
```
New MQTT message: rf/send/impuls .. {"systemcode":24,"programcode":2,"on":1}
transmit rf signal {"systemcode":24,"programcode":2,"on":1} with protocol impuls
transmitted pulse train with 50 pulses
```

You can also connect rfReceiverPin with rfTransmitterPin via a wire. By enabling `rfEchoMessages` you should get:
```
New MQTT message: rf/send/impuls .. {"systemcode":24,"programcode":2,"on":1}
transmit rf signal {"systemcode":24,"programcode":2,"on":1} with protocol impuls
transmitted pulse train with 50 pulses
rf signal received: {"systemcode":24,"programcode":2,"state":"on"} protocol=impuls status=0 repeats=1 deviceID=
rf signal received: {"systemcode":24,"programcode":2,"state":"on"} with protocol impuls
Publish MQTT message: rf/recv/impuls retain=0 .. {"systemcode":24,"programcode":2,"state":"on"}
rf signal received: {"systemcode":24,"programcode":2,"state":"on"} protocol=impuls status=3 repeats=103 deviceID=
rf signal received: {"systemcode":24,"programcode":2,"state":"on"} protocol=impuls status=3 repeats=104 deviceID=
rf signal received: {"systemcode":24,"programcode":2,"state":"on"} protocol=impuls status=3 repeats=105 deviceID=
rf signal received: {"systemcode":24,"programcode":2,"state":"on"} protocol=impuls status=3 repeats=106 deviceID=
rf signal received: {"systemcode":24,"programcode":2,"state":"on"} protocol=impuls status=3 repeats=107 deviceID=
rf signal received: {"systemcode":24,"programcode":2,"state":"on"} protocol=impuls status=3 repeats=108 deviceID=
```

If your esp crashes during processing a MQTT message, please check your power supply.

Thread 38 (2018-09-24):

RC switch to MQTT

denxhun, 2018-09-24:
Hi,

First of all this is a great project, I really like it.
May I miss something or the program intentionally not forwarding decoded switch messages to MQTT?
For example I see the following on the logs:
```
rf signal received: {"id":89,"temperature":21.61,"humidity":49.00,"battery":1,"channel":1} protocol= tfa status=0 repeats=1 deviceID=89
rf signal received: {"id":89,"temperature":21.61,"humidity":49.00,"battery":1,"channel":1} with protocol tfa deviceID=89
Publish MQTT message: rf434/recv/tfa/89 retain=1 .. {"id":89,"temperature":21.61,"humidity":49.00,"battery":1,"channel":1}
rf signal received: {"id":6,"unit":5,"state":"off"} protocol= conrad_rsl_switch status=0 repeats=1 deviceID=6
rf signal received: {"id":198,"temperature":16.16,"humidity":48.00,"battery":1,"channel":3} protocol= tfa status=0 repeats=1 deviceID=198
```

Is it possible to forward the Conrad switch messages to the MQTT - to let the homeassistant process it?

Thanks,
Denes

puuu, 2018-11-02:
All received, recognised (=able to decode by an enabled RF protocol) and proved signals are forwarded as MQTT message.

All your shown messages have `status=0` [which mean it is the first received signal](https://github.com/puuu/ESPiLight/blob/master/src/ESPiLight.h#L33). To be proven, a message must received twice (Usually, all rf sender will send the same rf message more then three times). I expect, either your signal is to weak, or the protocol is unknown and you see by noise manipulated signals.

Closed 2019-01-22.

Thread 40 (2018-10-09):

How to debug decoding

elbow, 2018-10-09:
Hi,

I installed MQTT433gateway with an RXB6 receiver.  Once I figured out that the data pin was mislabeled on my module I am getting something out of it.

But I'm not sure how to go about debugging reception.

I have some 4 button 433.92MHz remotes - they are supposed to be Sonoff compatible.

When I press buttons on the one remote the log shows:

rf signal received: {"id":"B15","unit":47,"state":"off"} with protocol rev2_switch deviceID=B15
rf signal received: {"id":"B15","unit":47,"state":"off"} with protocol rev2_switch deviceID=B15
(etc).

It doesn't matter which button I press - the display is the same.  How do I distinguish the buttons?

I also have some 433.92MHz PIRs, but the gateway doesn't show anything when they go off.

So how do I get started with debugging?

Thanks,
Steve

puuu, 2018-11-02:
For debugging, you can enable the `protocolRaw` debug flag in the web frontend, this will show the received raw signals.

But I am afraid that your remote may not be supported and the `rev2_switch` protocol is only similar to yours.

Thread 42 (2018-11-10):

Can't connect to Mqtt broker for FW > 1.0.0

torwag, 2018-11-10:
Hi,
after recompiling and flashing, the gateway can't connect to the MQTT Broker.

1. Set-up
Mosquito Broker on a HASS.IO-based HA RPi Server
Wemos d1mini for the gateway  v0.1.0-19-ge818a313
Firmware build was the current version from GIT
2. Error Message in the logs
From the Gateway:
Try to (re)connect to MQTT broker
MQTT connect failed!
From the Mosquito mqtt Broker log:
1541889226: Socket error on client <unknown>, disconnecting.
1541889231: New connection from 192.168.3.129 on port 1883.

I use a login for MQTT but tried as well without login and anonymous login without success.
Reversing back to 1.0.0 works with the given login credentials.

torwag, 2018-11-11:
BTW, I started all this upgrade mess, as suddenly my door sensors was not recognised any more. Formerly, they were identified as quigg_gt9000 devices. Strangely, they are now never pop up as those in the debug log. Albeit I noticed much more noise and other messages which might be noise as well as I do not own any of the devices which pop up.
Maybe my unit is faulty I check and flash another wemos lets see.

puuu, 2018-11-12:
The glup problem can be solved by deleting `web/node_modules` and `web/package-lock.json`.

I use the same library versions and can not reproduce your MQTT problem with PlatformIO 3.6.2a2 and espressif8266 1.8.0.

torwag, 2018-11-13:
Ok I am a step further.
First of all, compiling an older version did not work for me. The ESP (d1_mini) does not boot up with an older firmware even, the compiling and flashing seems ok.
Back on master I figured out that the deviceName seems to be the problem.

E.g. if I use 'MQTT433Gateway' as device name (without the quotes). I get repeating
```
Try to (re)connect to MQTT broker
MQTT connect failed!

```
from the Gateway logs and

```
1542119945: New connection from 192.168.3.129 on port 1883.
1542119945: Socket error on client <unknown>, disconnecting.

```
From the mosquitto broker logs.

What made me suspicious was the <unknown>
In fact if I change the name to anything shorter or equal to 5 characters the connection happens instantly with:
```
Applying config settings.
MQTT instance removed.
Try to (re)connect to MQTT broker
MQTT connected.
MQTT subscribe to topic: rf434/send/+
MQTT subscribed.
MQTT instance created.
MDNS service registered.
Saving config file.
```
in the gateway logs and
```
1542120375: New connection from 192.168.3.129 on port 1883.
1542120375: New client connected from 192.168.3.129 as test1 (c1, k15, u'iot').
1542120375: Will message specified (76 bytes) (r1, q0).
1542120375: 	test1/state
1542120375: Sending CONNACK to test1 (0, 0)
1542120375: Received SUBSCRIBE from test1
1542120375: 	rf434/send/+ (QoS 0)
1542120375: test1 0 rf434/send/+
1542120375: Sending SUBACK to test1
1542120375: Received PUBLISH from test1 (d0, q0, r1, m0, 'test1/state', ... (75 bytes))
```
in the broker logs.
Interestingly, 5 characters is exactly what by standard 'rf434' is used.

That tells me that either the Gateway somehow chokes up on the device name or that the broker can't deal with it. I will test further...

puuu, 2018-11-14:
Congratulation, you found a bug! It is related to #37.

PubSubClient define `MQTT_MAX_PACKET_SIZE` with [128](https://github.com/knolleary/pubsubclient/blob/master/src/PubSubClient.h#L26).

The connect package length is about:
> 10 [Header] + len(clientID) + 2 + len(lastWillTopic) + 2 + len(lastWillMessage) + 2

Optionally we need authentication:
>  len(username) + 2 + len(password) + 2

with [len(lastWillTopic) = len(clientID) + 6](https://github.com/puuu/MQTT433gateway/blob/master/lib/MQTT/MqttClient.cpp#L66) and our [long lastWillMessage](https://github.com/puuu/MQTT433gateway/blob/master/lib/MQTT/MqttClient.cpp#L59) (can be 76 long with a "dirty" git state), we easily hit the 128 byte package size.

PubSubClient simply [silently fails](https://github.com/knolleary/pubsubclient/blob/master/src/PubSubClient.h#L86) if the package gets to long.

Please try to add `-DMQTT_MAX_PACKET_SIZE=256` to `build_flags` in `platformio.ini`.

torwag, 2018-11-16:
Hi,
great, so can I give the bug a name :)

I tried quickly your suggested solution, but it did not work out. Maybe I have to run some sort of pio clean to make sure it gets recompiled with the new build-flags.
However, I couldn't find anything related to this.
In the logs the flag is right at place

puuu, 2018-11-16:
I increased the MQTT_MAX_PACKET_SIZE to 256  in commit 802b2adb1136d2ad5dc7b4d9295db6192aef32d9. This issue was closed automatically. In my test I can use long `deviceName`s after applying this commit. If you feel this issue is not fixed, please reopen it!

torwag, 2018-11-16:
Can confirm it is working now. Problem was that, in the path of testing, I changed some settings in the broker, which I had to undo too.

ben-woo, 2019-04-29:
IBM is not user-friendly that's the reason they're loosing to MS.

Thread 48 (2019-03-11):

Oregon Sensors supported?

kroon040, 2019-03-11:
Hi,

Is there a way that oregon sensors will be supported?

pilight supports it, but I can't find it in the web interface

https://wiki.pilight.org/oregon

puuu, 2019-03-12:
Unfortunately, the oregon protocol is not supported. It is also not supported by pilight. The wiki page you referenced is not the official list of [supported protocols] (https://manual.pilight.org/protocols/433.92/index.html) and points to a fork that is not actively developed.

I will close this issue because it is a duplicate of puuu/ESPiLight#27.

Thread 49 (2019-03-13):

Is Acurite Sensors supported?

alexsahka, 2019-03-13:
Is this supports Acu-Rite 00606TX Outdoor Temperature Sensor?
https://github.com/mikepparks/pilight-protocols

Currently, I'm using the RFLink Gateway for these sensors, but would be nice to use standalone MQTT gateway.

puuu, 2019-03-18:
A protocol with these filenames is not included in the ESPiLight, neither in the official pilight sources.

You may can try to add these files to `src/pilight/libs/pilight/protocols/433.92` of your local ESPiLight library and add lines to `src/pilight/libs/pilight/protocols/protocol_header.h` and `src/pilight/libs/pilight/protocols/protocol_init.h`.

But the best way is, to let the author submit these driver to pilight via pull request.

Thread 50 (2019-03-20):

no matching function for call to 'UpdaterClass::printError(ArduinoSimpleLogging::LogTarget&)'

m4rcu5, 2019-03-20:
Hi,

I am trying to compile the latest master branch for the `d1_mini` board, but it fails in the following errors:

```
lib/WebServer/ConfigWebServer.cpp: In member function 'void ConfigWebServer::onFirmwareUpload()':
lib/WebServer/ConfigWebServer.cpp:242:36: error: no matching function for call to 'UpdaterClass::printError(ArduinoSimpleLogging::LogTarget&)'
Update.printError(Logger.info);
^
lib/WebServer/ConfigWebServer.cpp:242:36: note: candidate is:
In file included from /home/mvandam/.platformio/packages/framework-arduinoespressif8266/cores/esp8266/Arduino.h:248:0,
from /home/mvandam/.platformio/packages/framework-arduinoespressif8266/libraries/ESP8266WiFi/src/WiFiClient.h:25,
from /home/mvandam/.platformio/packages/framework-arduinoespressif8266/libraries/ESP8266WiFi/src/ESP8266WiFi.h:39,
from /home/mvandam/.platformio/packages/framework-arduinoespressif8266/libraries/ESP8266WebServer/src/ESP8266WebServer.h:29,
from lib/WebServer/ConfigWebServer.cpp:30:
/home/mvandam/.platformio/packages/framework-arduinoespressif8266/cores/esp8266/Updater.h:75:10: note: void UpdaterClass::printError(Stream&)
void printError(Stream &out);
^
/home/mvandam/.platformio/packages/framework-arduinoespressif8266/cores/esp8266/Updater.h:75:10: note:   no known conversion for argument 1 from 'ArduinoSimpleLogging::LogTarget' to 'Stream&'
lib/WebServer/ConfigWebServer.cpp:247:36: error: no matching function for call to 'UpdaterClass::printError(ArduinoSimpleLogging::LogTarget&)'
Update.printError(Logger.info);
^
lib/WebServer/ConfigWebServer.cpp:247:36: note: candidate is:
In file included from /home/mvandam/.platformio/packages/framework-arduinoespressif8266/cores/esp8266/Arduino.h:248:0,
from /home/mvandam/.platformio/packages/framework-arduinoespressif8266/libraries/ESP8266WiFi/src/WiFiClient.h:25,
from /home/mvandam/.platformio/packages/framework-arduinoespressif8266/libraries/ESP8266WiFi/src/ESP8266WiFi.h:39,
from /home/mvandam/.platformio/packages/framework-arduinoespressif8266/libraries/ESP8266WebServer/src/ESP8266WebServer.h:29,
from lib/WebServer/ConfigWebServer.cpp:30:
/home/mvandam/.platformio/packages/framework-arduinoespressif8266/cores/esp8266/Updater.h:75:10: note: void UpdaterClass::printError(Stream&)
void printError(Stream &out);
^
/home/mvandam/.platformio/packages/framework-arduinoespressif8266/cores/esp8266/Updater.h:75:10: note:   no known conversion for argument 1 from 'ArduinoSimpleLogging::LogTarget' to 'Stream&'
lib/WebServer/ConfigWebServer.cpp:254:36: error: no matching function for call to 'UpdaterClass::printError(ArduinoSimpleLogging::LogTarget&)'
Update.printError(Logger.info);
^
lib/WebServer/ConfigWebServer.cpp:254:36: note: candidate is:
In file included from /home/mvandam/.platformio/packages/framework-arduinoespressif8266/cores/esp8266/Arduino.h:248:0,
from /home/mvandam/.platformio/packages/framework-arduinoespressif8266/libraries/ESP8266WiFi/src/WiFiClient.h:25,
from /home/mvandam/.platformio/packages/framework-arduinoespressif8266/libraries/ESP8266WiFi/src/ESP8266WiFi.h:39,
from /home/mvandam/.platformio/packages/framework-arduinoespressif8266/libraries/ESP8266WebServer/src/ESP8266WebServer.h:29,
from lib/WebServer/ConfigWebServer.cpp:30:
/home/mvandam/.platformio/packages/framework-arduinoespressif8266/cores/esp8266/Updater.h:75:10: note: void UpdaterClass::printError(Stream&)
void printError(Stream &out);
^
/home/mvandam/.platformio/packages/framework-arduinoespressif8266/cores/esp8266/Updater.h:75:10: note:   no known conversion for argument 1 from 'ArduinoSimpleLogging::LogTarget' to 'Stream&'
```

I've also tried the `esp12e` board, which fails on the exact same error.

m4rcu5, 2019-03-21:
Sorry, Ignore me :man_facepalming:

I totally forgot that I did not use PlatformIO for a while on this machine and all libraries were out-dated.
Tracking back to this change https://github.com/esp8266/Arduino/pull/4117/files, made me look at the library version.
```
Uninstalling framework-arduinoespressif8266 @ 1.20400.0: 	[OK]
PackageManager: Installing framework-arduinoespressif8266 @ ~2.20500.0
Downloading  [####################################]  100%  
Unpacking  [####################################]  100%
framework-arduinoespressif8266 @ 2.20500.190223 has been successfully installed!
```

And all is working!

Closed 2019-03-21.

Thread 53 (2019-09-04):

wont let be build web

pipppy1, 2019-09-04:
Attempting to build webpage...
WindowsError: [Error 2] The system cannot find the file specified:
  File "C:\python27\lib\site-packages\platformio\builder\main.py", line 124:
    env.SConscript(item, exports="env")
  File "C:\Users\phill\.platformio\packages\tool-scons\script\..\engine\SCons\Script\SConscript.py", line 541:
    return _SConscript(self.fs, *files, **subst_kw)
  File "C:\Users\phill\.platformio\packages\tool-scons\script\..\engine\SCons\Script\SConscript.py", line 250:
    exec _file_ in call_stack[-1].globals
  File "C:\Users\phill\Desktop\build\MQTT433gateway-0.2.0\MQTT433gateway-0.2.0\scripts\build_web.py", line 34:
    build_web()
  File "C:\Users\phill\Desktop\build\MQTT433gateway-0.2.0\MQTT433gateway-0.2.0\scripts\build_web.py", line 29:
    check_call(["npm", "install"])
  File "c:\python27\lib\subprocess.py", line 185:
    retcode = call(*popenargs, **kwargs)
  File "c:\python27\lib\subprocess.py", line 172:
    return Popen(*popenargs, **kwargs).wait()
  File "c:\python27\lib\subprocess.py", line 394:
    errread, errwrite)
  File "c:\python27\lib\subprocess.py", line 644:
    startupinfo)

pipppy1, 2019-09-04:
mine is esp 01 1meg  puya
but wont let me build the 2.0 web . but it lets me buld the 1.0 web

puuu, 2019-09-04:
Did you have [npm/Node.js](https://www.npmjs.com/get-npm) installed?

Basically, the build should not fail, if npm is not available, but I never tested it on Windows systems.

pipppy1, 2019-09-04:
i will try and install now

pipppy1, 2019-09-04:
nope i think its a problem with travis

pipppy1, 2019-09-04:
please could you build me a version for the esp01 1meg with puya memory support
with thanks

puuu, 2019-09-05:
Are you sure that npm is installed and PATH is set correctly? What is the result of `npm -v` in the console.

Building the web front end is optional and should only give a warning if npm is not available. Obviously, this check fails on your system. It would be nice if you could investigate the problem since I can not test under a Windows environment.

Anyway, the building the web front end is optional. You can simply remove `pre:scripts/build_web.py` from [platformio.ini](https://github.com/puuu/MQTT433gateway/blob/master/platformio.ini#L18).

Your second issue is with your board. Please explain what your problem is and why the binaries do not work. If possible, show a way (pull requests are welcome) how MQTT433gateway can be made compatible for more boards.

pipppy1, 2019-09-06:
System update
Current version: unknown
Build with:
ArduinoJson: 6.12.0
ArduinoSimpleLogging: 0.2.2
ESPiLight: 0.16.2
PlatformIO: 4.1.0a1
PubSubClient: 2.7
Syslog: 2.0.0
WebSockets: 2.2.0
WifiManager: 0.15-beta
espressif8266: 2.2.3
had to install gilp.js

pipppy1, 2019-09-06:
You can also edit the cores/esp8266/Esp.h file to set the define to 1.

 #ifndef PUYA_SUPPORT
   #define PUYA_SUPPORT 1
 #endif

pipppy1, 2019-09-06:
built and working esp01 1m with  puya memory support

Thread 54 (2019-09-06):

Not accessible by iPhone?

codegrau, 2019-09-06:
I'm trying to log into my gateway with an iPhone but can’t access the Frontend (back to http auth. Dialog).

Any idea how to solve this?

puuu, 2019-09-30:
Are you using the latest version of MQTT433gateway?

MQTT433gateway uses digest authentication to prevent the password from being sent as plain text on every Web request.

I do not have access to iOS devices for testing. There was a problem with iOS in combination with the esp8266 platform: esp8266/Arduino#4717. If you still have problems, this should be fixed upstream.

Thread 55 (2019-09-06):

Restart device per MQTT

codegrau, 2019-09-06:
Would be cool to restart the device per MQTT command.

puuu, 2019-09-30:
Why should that be necessary? I do not understand the use for it.

Did you have problems with the stability of MQTT433gateway? If so, please report your issue in detail.

Closed 2019-09-30.

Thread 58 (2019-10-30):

Open settings file for write failed

bphermansson, 2019-10-30:
I'm running on a ESP-01. I've checked that the SPIFFS is working with the CheckFlashConfig-sketch:

```
18:42:58.258 -> Flash real id:   001440E0
18:42:58.258 -> Flash real size: 1048576 bytes
18:42:58.258 ->
18:42:58.258 -> Flash ide  size: 1048576 bytes
18:42:58.258 -> Flash ide speed: 40000000 Hz
18:42:58.258 -> Flash ide mode:  DOUT
18:42:58.258 -> Flash Chip configuration ok.
```

But MQTT433gateway fails to save settings from the web gui:

`Open settings file for write failed!
`
Ideas?

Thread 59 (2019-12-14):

Which one to choose?

fliphess, 2019-12-14:
Hey @puuu !

I've recently bought a sonoff rf bridge which I modded to use the [direct mod](https://github.com/xoseperez/espurna/wiki/Hardware-Itead-Sonoff-RF-Bridge---Direct-Hack) which gives me in effect an esp8266 and some rf hardware in a nice plastic box.

I saw your engagement in the openmqttgateway project and after that I noticed this project too and now I'm not sure which one to choose if I don't need any bluetooth, IR and sensor fucntionality (if that was the case I'd choose the openmqttgateway instantly).

Both projects share the same rf library for pilight and this project is already using the mqtt convention that I am looking for.

You seem to know both projects very well and as both seem well maintained and intensively documented projects in which lot's of effort is put,  I'm not sure which is the one that suits best to my sonoff rf bridge.

Can you shine a little light on the main differences? Is it mostly the additional functionality for sensors and other RF libraries that can be used with the openmqttgateway or is there more functionality I need to know of before I make a choice?

(And off course thanks so much for creating the pilight arduino RF library!)

fliphess, 2019-12-15:
Closing this after reading #35 (I think this project  (MQTT433gateway) is more suitable to my needs as it's less bulky, memory hungry and more focussed on the task i want it to perform rather than all the sensory stuff :)

Closed 2019-12-15.

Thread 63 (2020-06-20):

Signal status VALID not working for some devices

redflo, 2020-06-20:
Hi, i had the problem, that i could only rarely get MQTT Messages from some devices even if they are really nearby. The Problem is, that these devices only send the messages 2 times (sometimes only one time?), and due to noise i often get only one message with valid checksum. But the "status" is set only to VALID if there are 2 messages in short time. Why? After changing VALID to FIRST in line 104 in RfHandler.cpp i get enough MQTT messages from the device even from a far range.

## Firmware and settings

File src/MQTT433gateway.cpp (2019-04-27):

/**
  MQTT433gateway - MQTT 433.92 MHz radio gateway utilizing ESPiLight
  Project home: https://github.com/puuu/MQTT433gateway/

  The MIT License (MIT)

  Copyright (c) 2016 Puuu

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
  THE SOFTWARE IS PROVIDED "AS IS", WITHOUT WARRANTY OF ANY KIND,
  EXPRESS OR IMPLIED, INCLUDING BUT NOT LIMITED TO THE WARRANTIES OF
  MERCHANTABILITY, FITNESS FOR A PARTICULAR PURPOSE AND
  NONINFRINGEMENT. IN NO EVENT SHALL THE AUTHORS OR COPYRIGHT HOLDERS
  BE LIABLE FOR ANY CLAIM, DAMAGES OR OTHER LIABILITY, WHETHER IN AN
  ACTION OF CONTRACT, TORT OR OTHERWISE, ARISING FROM, OUT OF OR IN
  CONNECTION WITH THE SOFTWARE OR THE USE OR OTHER DEALINGS IN THE
  SOFTWARE.
*/

#include <ESP8266httpUpdate.h>
#include <ESP8266mDNS.h>
#include <FS.h>

#include <ArduinoSimpleLogging.h>
#include <WiFiManager.h>

#include <ConfigWebServer.h>
#include <MqttClient.h>
#include <RfHandler.h>
#include <Settings.h>
#include <StatusLED.h>
#include <SyslogLogTarget.h>
#include <SystemHeap.h>
#include <SystemLoad.h>

WiFiClient wifi;

Settings settings;
ConfigWebServer *webServer = nullptr;
MqttClient *mqttClient = nullptr;
RfHandler *rf = nullptr;
SyslogLogTarget *syslogLog = nullptr;
StatusLED *statusLED = nullptr;
SystemLoad *systemLoad = nullptr;
SystemHeap *systemHeap = nullptr;

void setupMqtt(const Settings &) {
  if (mqttClient != nullptr) {
    delete mqttClient;
    mqttClient = nullptr;
    Logger.debug.println(F("MQTT instance removed."));
  }
  if (!settings.hasValidPassword()) {
    Logger.warning.println(
        F("No valid config password set - do not connect to MQTT!"));
    return;
  }
  if (settings.mqttBroker.length() <= 0) {
    Logger.warning.println(F("No MQTT broker configured yet"));
    return;
  }

  mqttClient = new MqttClient(settings, wifi);
  mqttClient->registerRfDataHandler(
      [](const String &protocol, const String &data) {
        if (rf) rf->transmitCode(protocol, data);
      });
  mqttClient->begin();
  Logger.info.println(F("MQTT instance created."));
}

void setupRf(const Settings &) {
  if (rf) {
    delete rf;
    rf = nullptr;
    Logger.debug.println(F("Rf instance removed."));
  }
  if (!settings.hasValidPassword()) {
    Logger.warning.println(
        F("No valid config password set - do not start RF handler!"));
    return;
  }

  rf = new RfHandler(settings);
  rf->registerReceiveHandler([](const String &protocol, const String &data) {
    if (mqttClient) {
      mqttClient->publishCode(protocol, data);
    }
  });
  rf->setEchoEnabled(settings.rfEchoMessages);
  rf->filterProtocols(settings.rfProtocols);
  rf->begin();
  Logger.info.println(F("RfHandler Instance created."));
}

void setupWebLog() {
  if (webServer) {
    if (settings.webLogLevel.length() > 0) {
      Logger.addHandler(Logger.stringToLevel(settings.webLogLevel),
                        webServer->logTarget());
    } else {
      Logger.removeHandler(webServer->logTarget());
    }
  }
}

void setupWebServer() {
  webServer = new ConfigWebServer(settings);

  webServer->registerSystemCommandHandler(F("restart"), []() {
    Logger.info.println(F("Restart device."));
    delay(100);
    ESP.restart();
  });
  webServer->registerSystemCommandHandler(F("reset_wifi"), []() {
    Logger.info.println(F("Reset wifi and restart device."));
    WiFi.disconnect(true);
    delay(100);
    ESP.restart();
  });
  webServer->registerSystemCommandHandler(F("reset_config"), []() {
    Logger.info.println(F("Reset configuration and restart device."));
    settings.reset();
    delay(100);
    ESP.restart();
  });
  webServer->registerProtocolProvider(RfHandler::availableProtocols);
  webServer->registerOtaHook([]() {
    Logger.debug.println(F("Prepare for oat update."));
    if (statusLED) statusLED->setState(StatusLED::ota);
    if (rf) {
      rf->filterProtocols(F("[]"));
      delete rf;
      rf = nullptr;
    }
    if (mqttClient) {
      delete mqttClient;
      mqttClient = nullptr;
    }
    WiFiUDP::stopAll();
  });
  webServer->registerDebugFlagHandler(
      F("protocolRaw"), []() { return rf && rf->isRawModeEnabled(); },
      [](bool state) {
        if (rf) rf->setRawMode(state);
      });
  webServer->registerDebugFlagHandler(
      F("systemLoad"), []() { return systemLoad != nullptr; },
      [](bool state) {
        if (state) {
          systemLoad = new SystemLoad(Logger.info);
        } else if (systemLoad) {
          delete systemLoad;
          systemLoad = nullptr;
        }
      });
  webServer->registerDebugFlagHandler(
      F("freeHeap"), []() { return systemHeap != nullptr; },
      [](bool state) {
        if (state) {
          systemHeap = new SystemHeap(Logger.info);
        } else if (systemHeap) {
          delete systemHeap;
          systemHeap = nullptr;
        }
      });

  webServer->begin();
  Logger.info.println(F("WebServer instance created."));

  setupWebLog();
}

void setupMdns(const Settings &s) {
  if (0 == settings.deviceName.length()) {
    return;
  }
  MDNS.close();
  if (!MDNS.begin(settings.deviceName.c_str())) {
    Logger.error.println(F("Error setting up MDNS responder"));
    return;
  }
  MDNS.addService("http", "tcp", 80);
  Logger.info.println(F("MDNS service registered."));
}

void setupStatusLED(const Settings &s) {
  delete statusLED;
  statusLED = new StatusLED(s.ledPin, s.ledActiveHigh);
  Logger.debug.print("Change status LED config: pin=");
  Logger.debug.print(s.ledPin);
  Logger.debug.print(" activeHigh=");
  Logger.debug.println(s.ledActiveHigh);
}

void setupWifi() {
  WiFiManager wifiManager;
  WiFi.hostname(settings.deviceName);
  wifiManager.setConfigPortalTimeout(180);
  wifiManager.setAPCallback([](WiFiManager *) {
    Logger.info.println(F("Start wifimanager config portal."));
    if (statusLED) statusLED->setState(StatusLED::wifimanager);
  });

  // Restart after we had the portal running
  wifiManager.setSaveConfigCallback([]() {
    Logger.info.println(F("Wifi config changed. Restart."));
    delay(100);
    ESP.restart();
  });

  if (!wifiManager.autoConnect(settings.deviceName.c_str(),
                               settings.configPassword.c_str())) {
    Logger.warning.println(F("Try connecting again after reboot"));
    ESP.restart();
  }
}

void setup() {
  Serial.begin(115200, SERIAL_8N1, SERIAL_TX_ONLY);
  Logger.addHandler(Logger.DEBUG, Serial);
  if (!SPIFFS.begin()) {
    Logger.error.println(F("Initializing of SPIFFS failed!"));
  }

  settings.registerChangeHandler(STATUSLED, setupStatusLED);
  settings.registerChangeHandler(BASE, setupMdns);
  settings.registerChangeHandler(MQTT, setupMqtt);
  settings.registerChangeHandler(RF_ECHO, [](const Settings &s) {
    Logger.debug.println(F("Configure rfEchoMessages."));
    if (rf) {
      rf->setEchoEnabled(s.rfEchoMessages);
    } else {
      Logger.warning.println(F("No Rf instance available"));
    }
  });
  settings.registerChangeHandler(RF_PROTOCOL, [](const Settings &s) {
    Logger.debug.println(F("Configure rfProtocols."));
    if (rf) {
      rf->filterProtocols(s.rfProtocols);
    } else {
      Logger.warning.println(F("No Rf instance available"));
    }
  });
  settings.registerChangeHandler(WEB_CONFIG, [](const Settings &s) {
    Logger.debug.println(F("Configure WebServer."));
    if (!webServer) {
      setupWebServer();
    }
  });
  settings.registerChangeHandler(SYSLOG, [](const Settings &s) {
    if (syslogLog) {
      Logger.removeHandler(*syslogLog);
      delete syslogLog;
      syslogLog = nullptr;
      Logger.debug.println(F("Syslog instance removed."));
    }
    if (s.syslogLevel.length() > 0 && s.syslogHost.length() > 0 &&
        s.syslogPort != 0) {
      syslogLog = new SyslogLogTarget();
      syslogLog->begin(s.deviceName, s.syslogHost, s.syslogPort);
      Logger.debug.println(F("Syslog instance created."));
      Logger.addHandler(Logger.stringToLevel(s.syslogLevel), *syslogLog);
    }
  });
  settings.registerChangeHandler(RF_CONFIG, setupRf);
  settings.registerChangeHandler(LOGGING, [](const Settings &s) {
    Logger.debug.println(F("Configure logging."));
    if (s.serialLogLevel.length() > 0) {
      Logger.addHandler(Logger.stringToLevel(settings.serialLogLevel), Serial);
    } else {
      Logger.removeHandler(Serial);
    }
    setupWebLog();
  });

  Logger.info.println(F("Load Settings..."));
  settings.load();

  setupStatusLED(settings);
  if (statusLED) statusLED->setState(StatusLED::wifiConnect);

  Serial.print(F("configPassword: "));
  Serial.println(settings.configPassword);
  setupWifi();

  // Notify all setting listeners
  settings.notifyAll();
  if (statusLED) statusLED->setState(StatusLED::startup);

  Logger.debug.println(F("Current configuration:"));
  settings.serialize(Logger.debug, true, false);
  Logger.debug.println();
  Logger.info.print(F("Listen on IP: "));
  Logger.info.println(WiFi.localIP());
}

void loop() {
  if (rf && mqttClient && mqttClient->isConnected()) {
    if (statusLED) statusLED->setState(StatusLED::normalOperation);
  } else {
    if (statusLED) statusLED->setState(StatusLED::requireConfiguration);
  }
  if (statusLED) {
    statusLED->loop();
  }

  MDNS.update();

  if (webServer) {
    webServer->loop();
  }

  if (mqttClient) {
    mqttClient->loop();
  }

  if (rf) {
    rf->loop();
  }

  if (systemLoad) {
    systemLoad->loop();
  }
  if (systemHeap) {
    systemHeap->loop();
  }
}

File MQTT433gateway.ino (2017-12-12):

/*
  MQTT433gateway - MQTT 433.92 MHz radio gateway utilizing ESPiLight
  Project home: https://github.com/puuu/MQTT433gateway/

  The MIT License (MIT)

  Copyright (c) 2016 Puuu

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
  THE SOFTWARE IS PROVIDED "AS IS", WITHOUT WARRANTY OF ANY KIND,
  EXPRESS OR IMPLIED, INCLUDING BUT NOT LIMITED TO THE WARRANTIES OF
  MERCHANTABILITY, FITNESS FOR A PARTICULAR PURPOSE AND
  NONINFRINGEMENT. IN NO EVENT SHALL THE AUTHORS OR COPYRIGHT HOLDERS
  BE LIABLE FOR ANY CLAIM, DAMAGES OR OTHER LIABILITY, WHETHER IN AN
  ACTION OF CONTRACT, TORT OR OTHERWISE, ARISING FROM, OUT OF OR IN
  CONNECTION WITH THE SOFTWARE OR THE USE OR OTHER DEALINGS IN THE
  SOFTWARE.
*/

#include "net-passwd.h"

#include <ESP8266WiFi.h>
#include <ESP8266httpUpdate.h>

#include <ESPiLight.h>
#include <PubSubClient.h>

#include "src/SHAauth/SHAauth.h"
#include "src/Heartbeat/Heartbeat.h"

#ifndef myMQTT_USERNAME
#define myMQTT_USERNAME nullptr
#define myMQTT_PASSWORD nullptr
#endif

const char *ssid = mySSID;
const char *password = myWIFIPASSWD;
const char *mqttBroker = myMQTT_BROCKER;
const char *mqttUser = myMQTT_USERNAME;
const char *mqttPassword = myMQTT_PASSWORD;

const int RECEIVER_PIN = 12;  // avoid 0, 2, 15, 16
const int TRANSMITTER_PIN = 4;
const int HEARTBEAD_LED_PIN = 0;

WiFiClient wifi;
PubSubClient mqtt(wifi);
Heartbeat beatLED(HEARTBEAD_LED_PIN);
ESPiLight rf(TRANSMITTER_PIN);
SHAauth otaAuth(myOTA_PASSWD);

const String mainTopic = String("rfESP_") + String(ESP.getChipId(), HEX);
const String globalTopic = "rf434";
bool logMode = false;
bool rawMode = false;
String otaURL = "";

void setupWifi() {
  delay(10);
  beatLED.on();
  // We start by connecting to a WiFi network
  Serial.println();
  Serial.print(F("Connecting to "));
  Serial.println(ssid);

  WiFi.mode(WIFI_STA);  // Explicitly set station mode
  WiFi.begin(ssid, password);

  while (WiFi.status() != WL_CONNECTED) {
    beatLED.off();
    delay(500);
    beatLED.off();
    delay(500);
    beatLED.on();
    Serial.print(F("."));
  }

  Serial.println();
  Serial.println(F("WiFi connected"));
  Serial.println(F("IP address: "));
  Serial.println(WiFi.localIP());
}

void transmitt(const String &protocol, const char *message) {
  Serial.print(F("rf send "));
  Serial.print(message);
  Serial.print(F(" with protocol "));
  Serial.println(protocol);

  if (protocol == F("RAW")) {
    uint16_t rawpulses[MAXPULSESTREAMLENGTH];
    int rawlen =
        rf.stringToPulseTrain(message, rawpulses, MAXPULSESTREAMLENGTH);
    if (rawlen > 0) {
      rf.sendPulseTrain(rawpulses, rawlen);
    }
  } else {
    rf.send(protocol, message);
  }
}

void mqttCallback(const char *topic_, const byte *payload_,
                  unsigned int length) {
  Serial.print(F("Message arrived ["));
  Serial.print(topic_);
  Serial.print(F("] "));
  for (unsigned int i = 0; i < length; i++) {
    Serial.print((char)payload_[i]);
  }
  Serial.println();

  String topic = topic_;
  char payload[length + 1];
  strncpy(payload, (char *)payload_, length);
  payload[length] = '\0';

  String sendTopic = globalTopic + F("/send/");
  if (topic.startsWith(sendTopic)) {
    transmitt(topic.substring(sendTopic.length()), payload);
  }
  sendTopic = mainTopic + F("/send/");
  if (topic.startsWith(sendTopic)) {
    transmitt(topic.substring(sendTopic.length()), payload);
  }
  if (topic == (mainTopic + F("/set/raw"))) {
    Serial.println(F("Change raw mode."));
    rawMode = payload[0] == '1';
  }
  if (topic == (mainTopic + F("/set/log"))) {
    Serial.println(F("Change log mode."));
    logMode = payload[0] == '1';
  }
  if (topic == (mainTopic + F("/ota/url"))) {
    otaURL = String(payload);
    mqtt.publish((mainTopic + F("/ota/nonce")).c_str(),
                 otaAuth.nonce().c_str());
  }
  if ((topic == (mainTopic + F("/ota/passwd"))) && (otaURL.length() > 7)) {
    if (otaAuth.verify(payload)) {
      beatLED.on();
      Serial.print(F("Start OTA update from: "));
      Serial.println(otaURL);
      rf.disableReceiver();
      t_httpUpdate_return ret = ESPhttpUpdate.update(otaURL);
      switch (ret) {
        case HTTP_UPDATE_FAILED:
          Serial.print(F("HTTP_UPDATE_FAILD Error ("));
          Serial.print(ESPhttpUpdate.getLastError());
          Serial.print(F("): "));
          Serial.println(ESPhttpUpdate.getLastErrorString());
          break;
        case HTTP_UPDATE_NO_UPDATES:
          Serial.println(F("HTTP_UPDATE_NO_UPDATES"));
          break;
        case HTTP_UPDATE_OK:
          Serial.println(F("HTTP_UPDATE_OK"));  // may not called ESPhttpUpdate
                                                // reboot the ESP?
          ESP.restart();
          break;
      }
      rf.enableReceiver();
    } else {
      Serial.println(F("OTA authentication failed!"));
    }
  }
}

void rfCallback(const String &protocol, const String &message, int status,
                int repeats, const String &deviceID) {
  Serial.print(F("RF signal arrived ["));
  Serial.print(protocol);
  Serial.print(F("]/["));
  Serial.print(deviceID);
  Serial.print(F("] ("));
  Serial.print(status);
  Serial.print(F(") "));
  Serial.print(message);
  Serial.print(F(" ("));
  Serial.print(repeats);
  Serial.println(F(")"));

  if (status == VALID) {
    String topic = globalTopic + String(F("/recv/")) + protocol;
    if (deviceID != nullptr) {
      topic += String('/') + deviceID;
    }
    mqtt.publish(topic.c_str(), message.c_str(), true);
  }
  if (logMode) {
    String topic = mainTopic + String(F("/log/")) + String(status) +
                   String('/') + protocol;
    mqtt.publish(topic.c_str(), message.c_str());
  }
}

void rfRawCallback(const uint16_t *pulses, int length) {
  if (rawMode) {
    String data = rf.pulseTrainToString(pulses, length);
    if (data.length() > 0) {
      Serial.print(F("RAW RF signal ("));
      Serial.print(length);
      Serial.print(F("): "));
      Serial.print(data);
      Serial.println();

      mqtt.publish((mainTopic + F("/recvRaw")).c_str(), data.c_str());
    }
  }
}

void reconnect() {
  beatLED.on();
  // Loop until we're reconnected
  while (!mqtt.connected()) {
    Serial.print(F("Attempting MQTT connection..."));
    // Attempt to connect
    if (mqtt.connect(mainTopic.c_str(), mqttUser, mqttPassword,
                     mainTopic.c_str(), 0, true, "offline")) {
      Serial.println(F("connected"));
      mqtt.publish(mainTopic.c_str(), "online", true);
      mqtt.subscribe((mainTopic + F("/set/+")).c_str());
      mqtt.subscribe((mainTopic + F("/ota/+")).c_str());
      mqtt.subscribe((mainTopic + F("/send/+")).c_str());
      mqtt.subscribe((globalTopic + F("/send/+")).c_str());
    } else {
      Serial.print(F("failed, rc="));
      Serial.print(mqtt.state());
      Serial.println(F(" try again in 5 seconds"));
      // Wait 5 seconds before retrying
      beatLED.off();
      delay(500);
      beatLED.on();
      delay(4500);
    }
  }
  beatLED.off();
}
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

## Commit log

2016-09-05 Initial import.
    [MQTT433gateway.fzz]
2016-09-07 hardware/MQTT433gateway.fzz: correct size of RX module
    The RF-LINK_RX Fritzing part has a wrong length. Changed by a corrected
    custom version.
    [MQTT433gateway.fzz]
2016-12-11 src/Heartbeat: New sub class that allows flashing of the LED.
2016-12-11 MQTT433gateway.ino: Add user selectable GPIO for the status LED
2016-12-11 MQTT433gateway.ino: Replace #define with const.
    In C++/Arduino const is prefered over #define.
    [MQTT433gateway.ino]
2016-12-16 MQTT433gateway.ino: correct spaces around operators
    [MQTT433gateway.ino]
2016-12-18 src/Heartbeat: refactor LED functionality in separate class
2016-12-18 src/Heartbeat/LED: new LEDOpenDrain class for open drain connection
    This allows reading a button connected to the same GPIO as the
    LED. Like Adafruit HUZZAH GPIO0.
2016-12-18 src/Heartbeat: make LEDOpenDrain default
2017-03-19 MQTT433gateway.ino: Explicitly set station mode
    hide ESP_xxxxx SSID
    Explicitly set the ESP8266 to be a WiFi-client, otherwise, it by default,
    would try to act as both a client and an access-point and could cause
    network-issues with your other WiFi-devices on your WiFi-network.
    [MQTT433gateway.ino]
2017-10-07 MQTT433gateway.ino: small typecasting fix
    change int to unsigned int to avoid compiler warning.
    [MQTT433gateway.ino]
2017-12-12 MQTT433gateway.ino: move setup() to correct position
    [MQTT433gateway.ino]
2017-12-12 lib/Heartbeat/LED.cpp: clang-format
2017-12-12 lib/Heartbeat/LED.h: clang-format
2017-12-12 LED: Add missing virtual destructor
2017-12-12 lib/Heartbeat/HeartbeatFlashing.h: replace arduino boolean.
2017-12-12 lib/Heartbeat/LED.cpp: replace arduino boolean.
2017-12-12 lib/Heartbeat/LED.h: replace arduino boolean.
2017-12-12 lib/SHAauth/SHAauth.cpp: replace arduino boolean.
2017-12-12 lib/SHAauth/SHAauth.h: replace arduino boolean.
2017-12-12 src/MQTT433gateway.cpp: replace arduino boolean.
    [MQTT433gateway.ino]
2017-12-12 lib/Heartbeat/LED.cpp: proper types for digital pin.
2017-12-12 LED: Make single argument constructors explicit
2017-12-12 lib/Heartbeat/LED.h: Use override instead virtual.
2017-12-12 Organize things as platformio project.
    PlatformIO is an ecosystem consisting of a buildsystem, a dependency-
    management for libraries, an ide and a lot more. It makes developing
    embedded projects very easy because it integrates all the tools and
    frameworks that are needed. A user just needs to install platformio and
    call
    $ platformio run
    to build the project. All the necessary frameworks, tools and libraries
    will be downloaded and correctly used.
    [MQTT433gateway.cpp]
2017-12-12 README.md: add usage for the PlatformIO environment.
    This adds a description, how to use the platformio build system to
    build the project in general or for a specific board.
2017-12-12 README.md: Mention old Arduino IDE branch
2017-12-12 src/MQTT433gateway.cpp: integrate Protocol filtering.
    This adds the protocol limitation feature of ESPiLight. Protocols are
    easilyselectable via MQTT message.
2017-12-12 README.md: Add documentation about protocol filtering.
2017-12-21 Debug: Print current config to serial
2017-12-21 MQTT: Use full match for MQTT set-topics
    We don't have partial matching in this case, so we can math the full
    part of the topic.
2017-12-21 Logging: Basic integration of ArduinoSimpleLogging
2017-12-21 Replace all Debug and DebugLn macros with ArduinoSimpleLogging.
    [MQTT433gateway.cpp]
2017-12-21 MQTT: Throttle reconnect attempts
    This is useful if the user set a wrong passwort. Otherwise the device
    will flood the server with reconnect attempts.
2017-12-21 Set board speed to 160MHz
2017-12-21 Settings: fix settings update bug
    Boolean AND expressions will be short circuit evaluation so the update
    for settings was only ever evaluated until the first difference in a
    group.
2017-12-21 Settings: Directly print to stream.
2017-12-21 Logging: bump ArduinoSimpleLogging version
2017-12-21 src/MQTT433gateway.cpp: Print error, if SPIFFS init failed.
    [MQTT433gateway.cpp]
2017-12-21 Restart on wifi config reset
    [MQTT433gateway.cpp]
2017-12-21 Wifi: remove static wifi config.
    The user should use the WifiManager to configure the device.
2017-12-21 Wifi: change wifi handling.
    This adapts PR #22.
    The wifimanager is only locally instantiated and all ressources are
    freed after the configuration. It also uses the device-name/config-pw
    from the settings for the AP-ssid/AP-password.
    The device will be rebooted if we have a new config. This should adress
    the concern that the heap gets fragmented by the config portal.
    [MQTT433gateway.cpp]
2017-12-21 Settings: do not initialize MQTT broker with defaults.
    Instead of forcing the user to change a header file for defaults he can
    just push the default config to the http endpoint after flashing the
    device.
    [MQTT433gateway.cpp]
2017-12-21 Print out the IP the device is listening on.
2017-12-21 Fix crash when MQTT wasn't instantiated.
    [MQTT433gateway.cpp]
2017-12-21 Frontend: add button to clear the log.
2017-12-22 MQTT433gateway.cpp: reorder statements.
    Should not make any difference here but better be correct :).
    [MQTT433gateway.cpp]
2017-12-22 MDNS: Use device name as mdns name.
2017-12-22 Settings: initialize deviceName to a common Name.
    This allows to reference a single name in the docs for unexperienced
    users that have most probably only one device anyway. It also helps to
    point to the right mdns-name.
    Everyone who has more than one devoce running can easily change it to
    something unique for the device.
2018-01-17 ArduinoJson: enable PROGMEM support
2018-01-17 Settings: change default device name.
2018-01-17 Fetch ArduinoSimpleLogging from the lib manager.
2018-01-17 Reboot ESP after settings reset.
    [MQTT433gateway.cpp]
2018-01-17 Frontend: Handle device reboot on settings reset.
2018-01-18 ConfigWebServer: use F() instead of PSTR() for ArduinoJSON calls
2018-01-18 ConfigWebServer: simplify string concatenation and switch to send_P
2018-01-18 platformio.ini: remove ARDUINOJSON_ENABLE_PROGMEM flag
2018-01-18 Frontend: give the upload button a meaningfull description
2018-01-30 LED: rearange includes
2018-01-30 Heartbeat/LED.cpp: reset pin correctly
2018-01-30 Heartbeat/LED.h: default destructor for LEDOpenDrain
2018-01-30 HeartbeatFlashing: switch flashing off in destructor
2018-01-30 Heartbeat(|Flashing): strictly use LED reference
2018-01-30 StatusLED: provide proper abstraction for the status LED
2018-01-30 Settings: manage status led settings
2018-01-30 Frontend: provide status LED settings
2018-01-30 README.md: document new status LED behaviour
2018-01-30 Settings: add settings for pullup on rf receiver pin
2018-01-30 SystemLoad: print loop iterations per time interval
2018-01-30 SystemHeap: print free Heap
2018-01-30 Frontend: remove #dbg-form-reset click event
    The reset button for debug does not exists anymore.
2018-01-30 RfHandler: print pilight errors to Logger.error
2018-02-06 MQTT433gateway: add missing return in setupMdns()
    [MQTT433gateway.cpp]
2018-02-06 MQTT433gateway: reset rf protocol list in otaHook
    [MQTT433gateway.cpp]
2018-02-08 MQTT433gateway: print configPassword on Serial
2018-02-08 Frontend: reopen WebSocket only if no ping timer is active
2018-02-08 Settings: request MQTT change on deviceName change
2018-02-08 Frontend: remove superfluous args in throttle()
2018-02-08 Frontend: clear websocket timer in ping()
2018-02-08 Frontend: name config reset button Reload
2018-02-23 Add documented support for the nodemcu platform for NodeMCU 0.9 boards
2018-09-03 platformio.ini: replace deprecated board_f_cpu with board_build.f_cpu
2018-09-03 lib/Settings/Settings.h: replace deprecated BUILTIN_LED with LED_BUILTIN
2018-11-02 WebServer: use Logger.info as target for Update.printError()
2018-11-02 Settings: Do not let JsonKey be in PROGMEM
    As a suggestion of ArduinoJson:
    https://arduinojson.org/v5/faq/how-to-reduce-memory-usage/
2018-11-16 Frontend: change url if deviceName is changed and mDNS is used
2018-11-19 lib/MQTT/MqttClient.cpp: publish current version to version topic
